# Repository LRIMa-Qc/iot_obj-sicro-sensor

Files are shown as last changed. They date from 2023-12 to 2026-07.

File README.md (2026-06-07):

# iot_obj-sicro-sensor

Authors : LRIMa (Laboratoire de Recherche Informatique de Maisonneuve)

## Repo composition

```bash
code/
├── actioneur       (esp32 code)
├── broadcaster     (sensor code [nrf52833])
├── central         (python BLE scanning and ALIVEcode integration)
└── central-nrf     (BLE receiver [nrf52840dongle])
schematic/
├── lrima-main/     (Main board KiCad project)
└── lrima-ground/   (Ground board KiCad project)
models/
└── sensor-casing/  (3D CAD models for enclosure)
```

### Physical device

The schematics and PCB were designed using [KiCad](https://www.kicad.org/) EDA software
There is a protective layer that needs to be applied on the ground part of the pcb to prevent corrosion

## Building

#### Tools needed

- VS Code
- [nRF Connect](https://www.nordicsemi.com/Products/Development-tools/nrf-connect-for-desktop)
- [nRF Connect VS Code extension](https://www.nordicsemi.com/Products/Development-tools/nRF-Connect-for-VS-Code)
- nRF toolchain `v3.2.4`
- nRF SDK `v3.2.4`
- J-Link
- Python 3.8+ (for central application)

#### Broadcaster

##### Preparing the environment

Before building the broadcaster program, you **must** make sure that you changed the `CONFIG_BLE_USER_DEFINED_MAC_ADDR` and the `CONFIG_BLE_USER_DEFINED_NAME` so that they are unique. Note that the `CONFIG_BLE_USER_DEFINED_NAME` must end with a number (ex : 01). If you need mac address, you can use this [mac address generator](https://dnschecker.org/mac-address-generator.php).

##### Building

The broadcaster uses the **sysbuild** system from NCS v3.2.4. To build the program for the nrf52833 using the [nRF Connect VS Code extension](https://www.nordicsemi.com/Products/Development-tools/nRF-Connect-for-VS-Code):

1. Open the broadcaster folder in VS Code
2. Use the nRF Connect extension to build using the `lrima_greenhouse_nrf52833` board
3. Flash using the [extension flashing options](https://nrfconnect.github.io/vscode-nrf-connect/get_started/quick_debug.html#how-to-flash-an-application)

Note: If flashing fails, use the `erase and flash` option to perform a full erase first.

###### J-Link setup

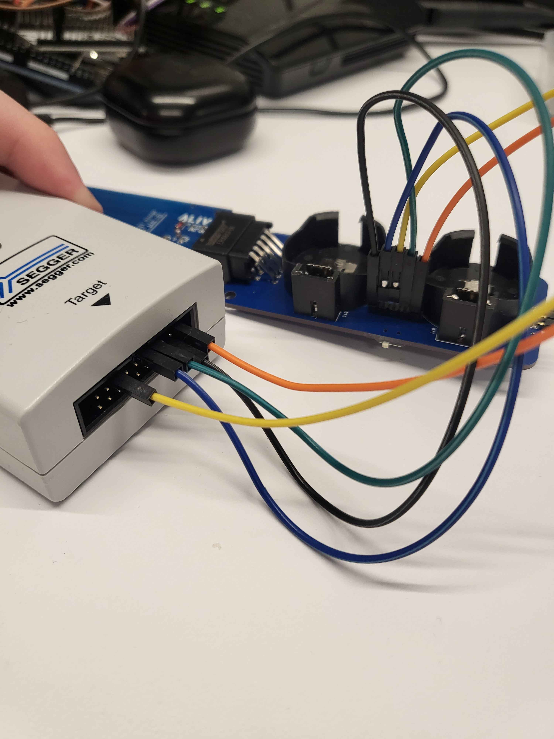
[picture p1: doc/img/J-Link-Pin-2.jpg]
J-Link setup

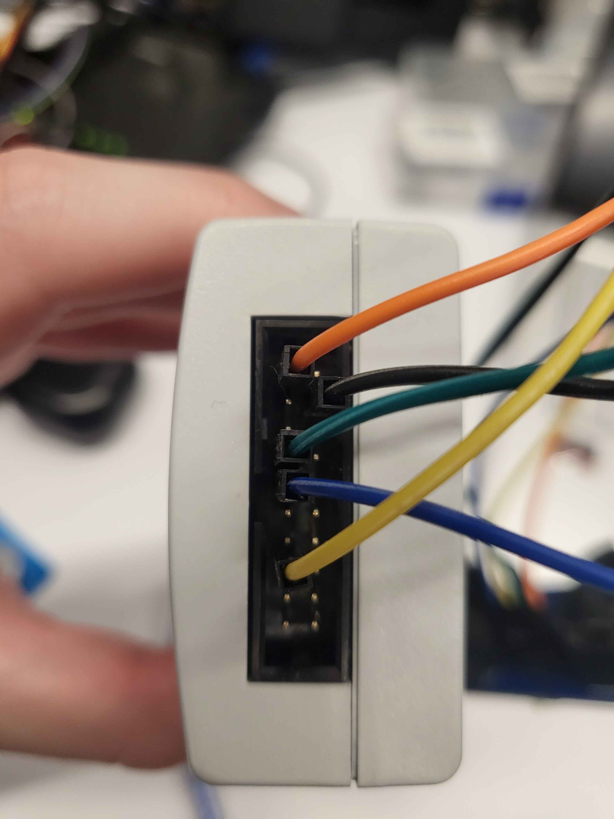
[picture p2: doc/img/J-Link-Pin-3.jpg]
J-Link setup 2

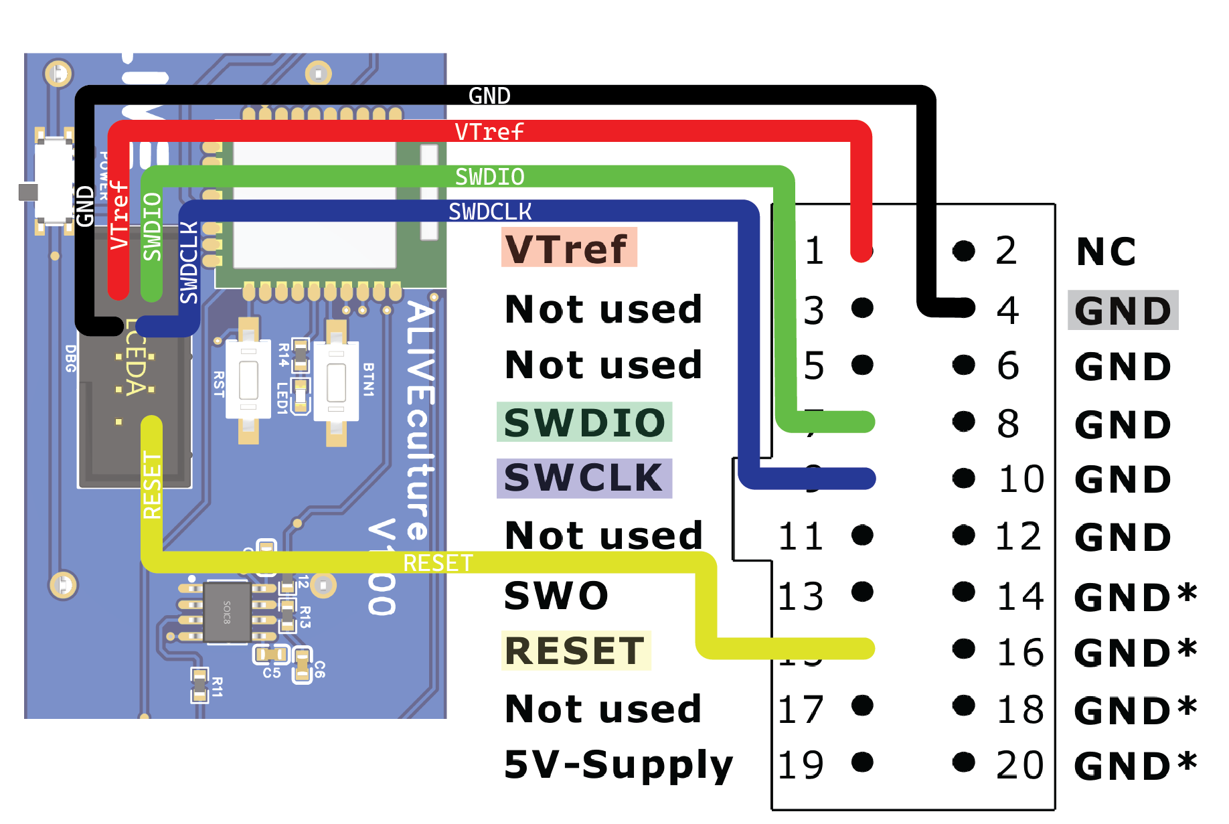
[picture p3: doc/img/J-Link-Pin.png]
J-Link setup 3


#### Firmware over the air update (DFU)

The board supports over-the-air firmware updates. To prepare an update:

1. Build the application as described above
2. Locate the signed image in the sysbuild app domain: `build/broadcaster/zephyr/zephyr.signed.bin`
3. Transfer this file to your phone
4. Press and hold button1 until the LED is on, then release
5. You will have up to 60 seconds (configurable via `CONFIG_BLE_DFU_ADV_DURATION_SEC`) to start the update
6. Use the [nRF Connect mobile app](https://www.nordicsemi.com/Products/Development-tools/nrf-connect-for-mobile) to connect to the device (named with your `CONFIG_BLE_USER_DEFINED_NAME`)
7. Go to the `DFU` tab and select `zephyr.signed.bin`
8. Press `Upload` and monitor the progress

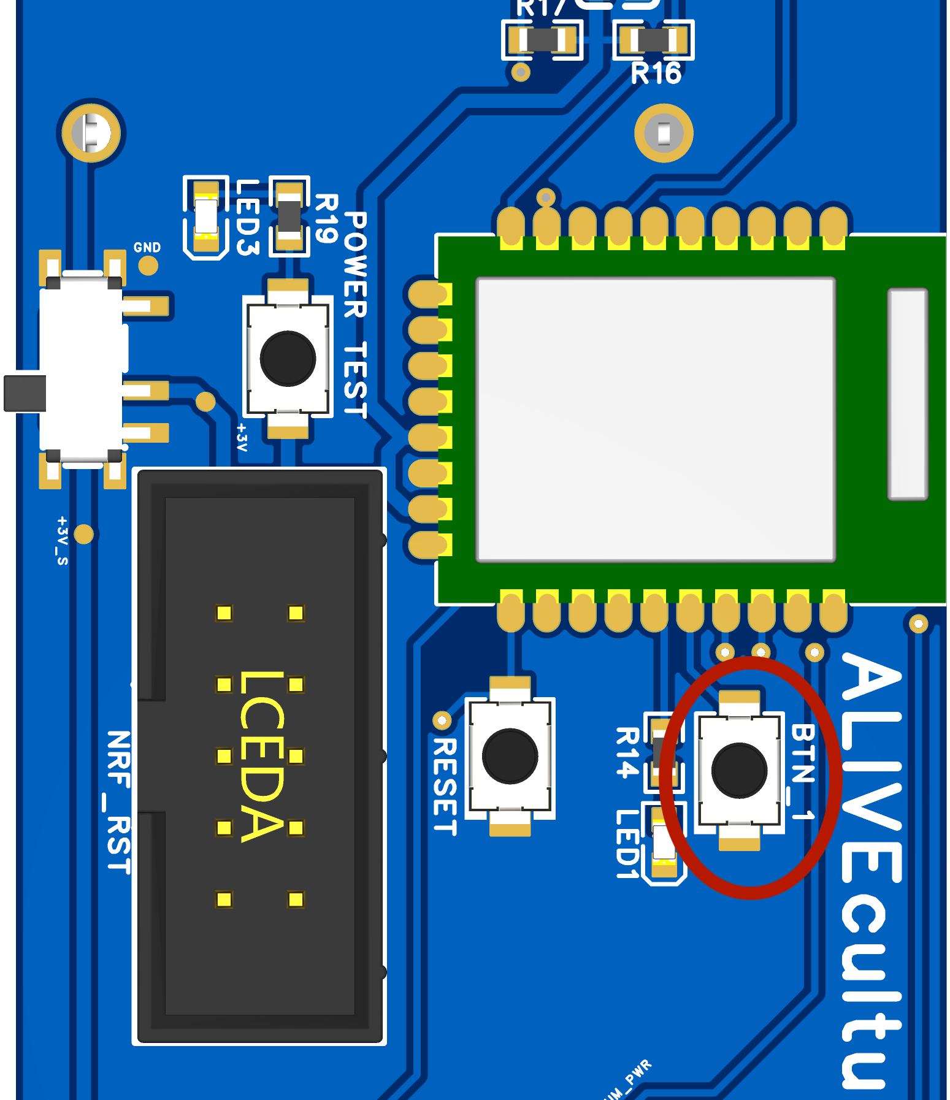
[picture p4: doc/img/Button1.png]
Button1


#### Device Functionality

The broadcaster uses a single BLE advertising workflow. It sends sensor data uplink and then opens a short scan window to receive a downlink sleep update when needed. The user can wake up the device at any time by pressing button1. There is never a connection established, and all communication is done through advertisements and scan responses.

##### Broadcaster

The broadcaster collects sensor data and transmits it BLE advertisements:

**Supported sensors:**

- Temperature/Humidity (SHT4X)
- Soil temperature/moisture/conductivity (STCC4)
- CO2 concentration

**Transmission behavior:**

- Sends data at intervals specified by `CONFIG_SENSOR_SLEEP_DURATION_SEC`
- Uses BLE advertising for the duration specified in `CONFIG_BLE_ADV_DURATION_SEC`
- Publishes a 29-byte service payload containing company ID, node ID, sequence, sleep duration, sensor values, and a presence bitmap
- Opens an active scan window after uplink to receive sleep updates sent by the central
- Beacon payload structure is shown below:

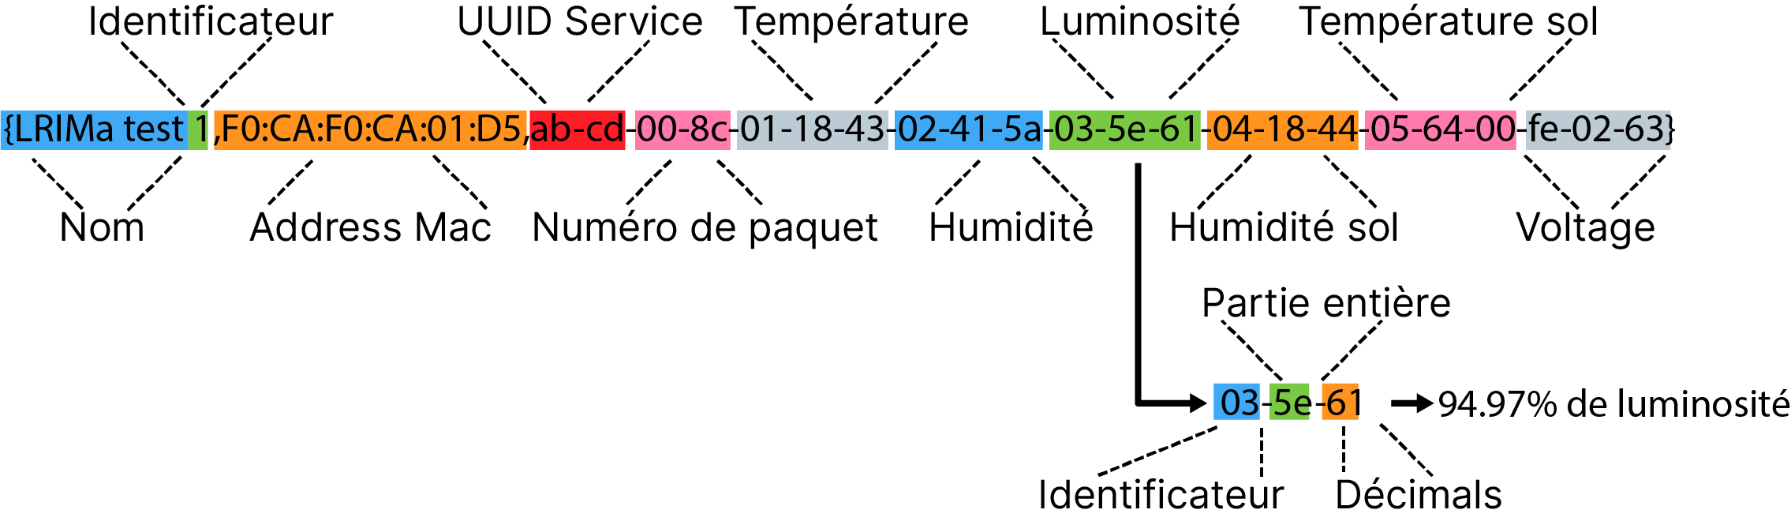
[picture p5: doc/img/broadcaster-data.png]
Broadcaster data.


> **Note:** The diagram above predates the latest payload format. See the broadcaster documentation for the full 29-byte layout and presence bitmap details.

### Central-nrf

The central-nrf firmware runs on the nRF52840 dongle to receive BLE broadcasts from the broadcaster.

**Building:**

1. Use the [nRF Connect VS Code extension](https://www.nordicsemi.com/Products/Development-tools/nRF-Connect-for-VS-Code) to build for `nrf52840dongle_nrf52840` board
2. Flash using the nRF Connect for Desktop programmer tools
3. Put the device in [DFU mode](https://infocenter.nordicsemi.com/index.jsp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)
4. Flash the `build/zephyr/zephyr.hex` file

### Central (Python Application)

The central application handles BLE scanning, data collection, and integration with ALIVEcode.

**Core modules:**

- `core/storage.py` - Persistent data management
- `core/payload.py` - Sensor data parsing and validation
- `core/aliot_sync.py` - ALIVEcode cloud integration
- `core/downlink_advertiser.py` - BlueZ D-Bus advertiser for sleep-time downlink frames
- `core/health.py` - System health monitoring
- `core/config.py` - Configuration management

**Setup and running:**

1. Plug the Central-nrf dongle into a computer or Raspberry Pi
2. Configure the application:
   - Copy `config.ini.example` to `config.ini`
   - Set your `object_id` and `auth_token` from your [ALIVEcode.ca](https://ALIVEcode.ca) IoT project

3. Install dependencies:

   ```bash
   # For Raspberry Pi 4
   pip install -r requirements_pi4.txt

   # For Raspberry Pi 5
   pip install -r requirements_pi5.txt
   ```

   (Using a Python virtual environment is recommended)

   `dbus-next` is required because downlink sleep updates are emitted through BlueZ D-Bus advertising APIs.

4. Run the application:

   ```bash
   python main.py
   ```

5. Power on the broadcaster devices

The application will automatically scan for broadcaster devices, collecting sensor data and synchronizing with ALIVEcode.
It publishes each node under `/doc/<device_index>` including `/doc/<device_index>/sleep_duration_sec`, and uses `/doc/sleep_time` as the desired target for downlink sleep updates.

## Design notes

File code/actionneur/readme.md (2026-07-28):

# Actionneur

## Description

This folder contains the code for the esp32 that controls relays from ALIVEcode.

## How to use

### Seting up the secrets

You must setup the `SECRET.h` file witht the `SSID` and `PASSWORD` of the wifi network you want to connect to.
Also you need to set the `AUTH_TOKEN` and `OBJECT_ID` from the device page on ALIVEcode.
The `SECRET.h` file should look like this:

```c++
/**
 * Fill in the credentials below
 * For the Wifi and the Aliot credentials
*/

// Setup wifi credentials
#define SSID "SSID"
#define PASSWORD "PASSWORD"

// Setup aliot credentials
#define AUTH_TOKEN "AUTH_TOKEN"
#define OBJECT_ID "OBJECT_ID"
```

### Setting up the relays

You need to setup the relays in the `main.cpp` file.

#### Defining the relays

The relays are defined in the `valves` array. like this:

```c++
const Valve valves[] = // Changed to an array
    {
        {
            .actionId = "valve_1",
            .pin = 2,
            .isPinInverted = true
        },
        {
            .actionId = "valve_2",
            .pin = 4,
            .isPinInverted = true
        }
    };
```

_Note : You can not have more relay than the value of `MAX_ACTION_COUNT` in `Aliot-C` (the default value is 5)_

- The `actionId` field is the id of the action _and_ the field value on ALIVEcode.
- The `pin` field is the pin number on the esp32.
- The `isPinInverted` field is used to invert the pin state. (If the relay is active when the pin is low, set this to `true`)

#### Adding the callbacks

For each relay you need to add the following bit of code:
`main.cpp` callback function:

```c++
// Function to be called when valve 1 state is changed on ALIVEcode
bool callbackValve1(const char* data) {

    Serial.print("New valve 1 state:");
    Serial.println(data);

    // Set valve 1 state
    setValveState(valves[0], stringToBool(data));

    return true;
}

void setup() {
    // ...

    // Add the callback to the valve 1
    addCallback(valves[0].actionId, callbackValve1);

    // ...
}
```

### Adding controls on AliveCode

1. Create a toggle component
2. Set the toggle to be controlled by the document with `actionID`
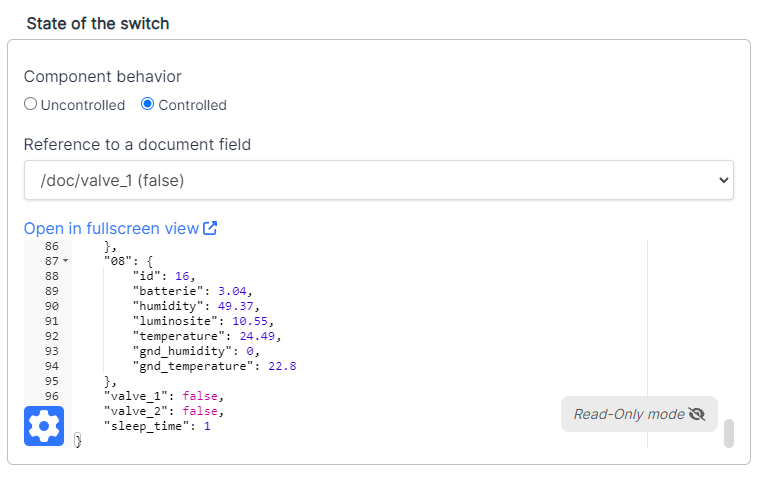
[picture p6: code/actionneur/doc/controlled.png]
controlled image
   
3. Set the Id of the action to the `actionID`
   ActionID image
4. Repeat 1-3 for each relay in the list

### Updating the wifi credentials remotely

The device exposes a `wifi_config` action that lets you push new wifi credentials from the ALIVEcode dashboard without re-flashing the device.

1. Create an action component with `actionID` set to `wifi_config`.
2. Configure the action's payload value to be a JSON string of the form:

   ```json
   { "ssid": "MyNetwork", "password": "MyPassword" }
   ```

3. When received, the device saves the new credentials to non-volatile storage (NVS) and switches to the new network. The `SSID`/`PASSWORD` values in `SECRET.h` are only used as a fallback on first boot, before any `wifi_config` action has ever been received; afterwards, the stored credentials always take precedence.

> **Warning**: if the new credentials are invalid, the device will fail to connect, restart, and retry with the same (bad) saved credentials on every subsequent boot — there is currently no automatic fallback to the last-known-good network. Double check the SSID/password before sending this action.

_Note: credential persistence relies on the ESP32 `Preferences` (NVS) API. On `esp8266`/`native` builds the `wifi_config` action is still registered and will switch networks for the current session, but nothing is persisted — the hardcoded `SECRET.h` credentials are used again on the next boot._

### Installing the libraries

The project uses platformio to manage the libraries. You can install it from [here](https://platformio.org/install/ide?install=vscode).
After installing platformio, you need to install the libraries. You can do this by opening the project in vscode and clicking on the `PlatformIO: Build` button in the bottom left corner. (The library installation should start automatically)

#### Libraries used

- [ArduinoJson](https://arduinojson.org/)
- [Aliot-C](https://github.com/LRIMa-Qc/aliot-c)
- [WiFiClientSecure](https://www.arduino.cc/en/Reference/WiFiClientSecure)
- [ArduinoHttpClient](https://www.arduino.cc/reference/arduinohttpclient/)

### Uploading

#### Connection

First plug the esp32 to your computer using a FTDI Mini Usb to Serial adapter [https://www.amazon.ca/dp/B0CBBKXVQV](https://www.amazon.ca/dp/B0CBBKXVQV)

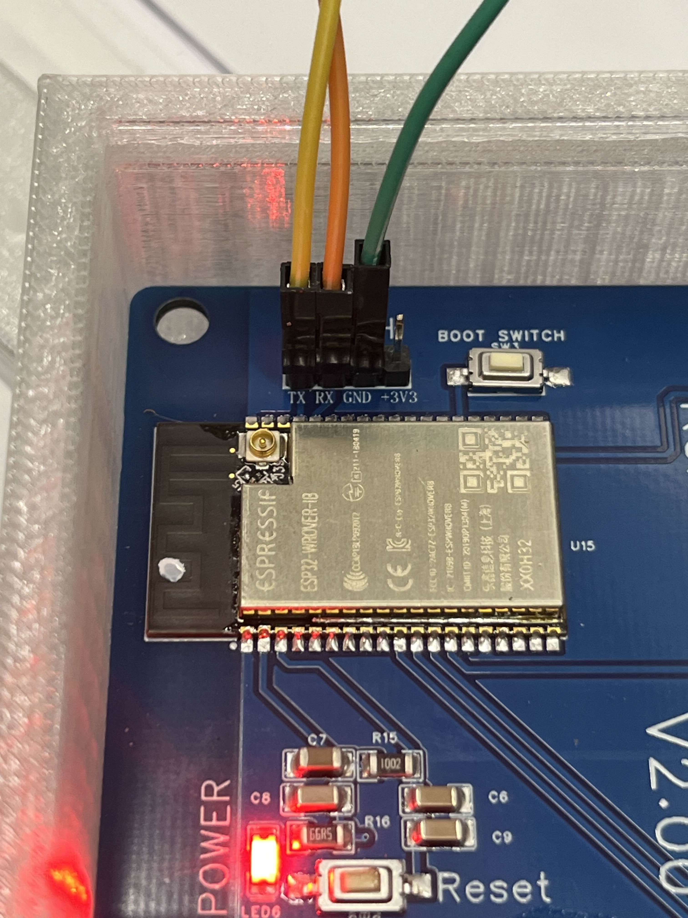
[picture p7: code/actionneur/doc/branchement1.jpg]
Branchements #1

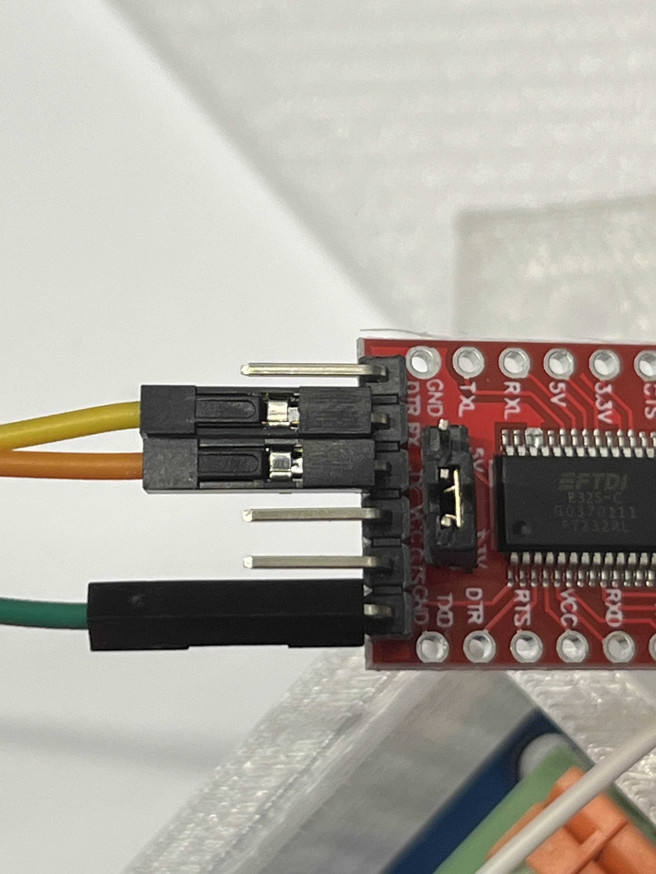
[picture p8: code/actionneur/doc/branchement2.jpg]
Branchements #2


See the table below for the connections:

| Relais | FTDI |
| --- | ---- |
| RX | TX |
| TX | RX |
| GND | GND  |

#### Uploading the code

You can upload the code to the esp32 by clicking on the `PlatformIO: Upload` button ( ➡️ ) in the bottom left corner of vscode. (You need to have the esp32 connected to your computer)

#### Relay board specific

1. You need to set the board in `Boot` mode to upload the code.
   > (You can do this by shorting the `BOOT` header before connecting the esp32 to power)
2. After the board is powered, you can unshort the `BOOT` header.
3. You need to make sure that all the `DIP` switches are set to the relay side.
   > (If you don't do it, the board won't flash properly. This is due to the fact that `PIN 12` must be set to `low`)

### Monitoring the serial output

You can monitor the serial output by clicking on the `PlatformIO: Serial Monitor` button ( 🔌 ) in the bottom left corner of vscode. (You need to have the esp32 connected to your computer)

### Connecting components (ex: Fans, Lights, etc.)

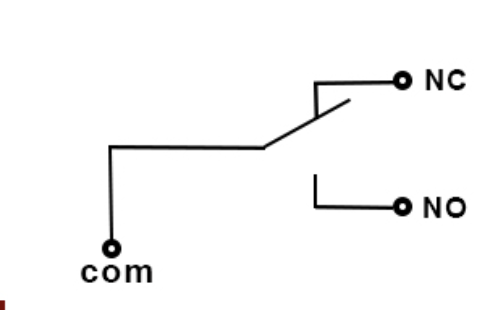
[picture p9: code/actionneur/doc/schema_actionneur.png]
Connection components


Connect into the COM (middle) the voltage source (anything between 0V to 220V) and the NO (Normally Open) the component you want to control. You can connect the NC (Normally Closed) to the component if you want to invert the relay state.

In simpler terms:

1. When the relay is activated, the power from the COM will be sent to the NO.
2. When the relay is deactivated, the power from the COM will be sent to the NC.

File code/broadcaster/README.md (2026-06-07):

# Broadcaster

## Flashing the board

### Tools needed

- VS Code
- [nRF Connect](https://www.nordicsemi.com/Products/Development-tools/nrf-connect-for-desktop)
- [nRF Command line tool](https://www.nordicsemi.com/Products/Development-tools/nRF-Command-Line-Tools/Download)
- [nRF Util](https://www.nordicsemi.com/Products/Development-tools/nrf-util)
- [nRF Connect VS Code extension](https://www.nordicsemi.com/Products/Development-tools/nRF-Connect-for-VS-Code)
- nRF toolchian `v3.2.4`
- nRF SDK `v.3.2.4`
- J-Link

### Preparing the environment

Before building the broadcaster program, you **must** make sure that you changed the `CONFIG_BLE_USER_DEFINED_MAC_ADDR` and the `CONFIG_BLE_USER_DEFINED_NAME` so that they are unique. Note that the `CONFIG_BLE_USER_DEFINED_NAME` must end with a number (ex : 01). If you need mac address, you can use this [mac address generator](https://dnschecker.org/mac-address-generator.php).

These values are used as defaults and are now persisted in flash (settings/NVS) on first boot. If you later change them in configuration, the device will keep the persisted values unless flash settings are erased.

### Building and flashing

To build the program for the nrf52833 you need to use the [NRFconnect](https://www.nordicsemi.com/Products/Development-tools/nRF-Connect-for-VS-Code) extension in vscode and then you just have to [follow the instructions](https://nrfconnect.github.io/vscode-nrf-connect/get_started/build_app_ncs.html#how-to-build-an-application) to build it using the `lrima_greenhouse_nrf52833/nrf52833` board target. After you need to flash it using the [option available in the extension](https://nrfconnect.github.io/vscode-nrf-connect/get_started/quick_debug.html#how-to-flash-an-application).

Note : If the board is giving out an error when flashing try these steps :

1. Check that the J-Link is detected by the computer (Drivers might be needed)
2. Check that the board has power (Use the led test button)
3. Check that the J-Link is properly connected to the board (You can try to press the reset button on the board, the J-Link led should be red when the button is pressed)
4. Try to flash the board using the `erase and flash` option
5. Verify the soldering of the board

To reset persisted settings (`sleep time`, `device name`, `device MAC`, `device node ID`) and re-apply values from `prj.conf`, you must use **erase and flash** (a normal flash keeps existing settings in NVS).

### Startup initialization behavior

When the broadcaster boots, the LED blinks while the remaining drivers are initialized. Once initialization completes, the LED is turned off.

If one of the startup initializations fails, the firmware logs the error, turns the LED on solid for 5 seconds, and then reboots the board.

#### J-Link setup

J-Link setup

### Firmware over the air update (DFU)

The board supports over-the-air updates (OTA) over BLE/MCUmgr.

1. Build the firmware as described above.
2. Use the signed application image from the sysbuild app domain:
   - `build/broadcaster/zephyr/zephyr.signed.bin` (single-image BLE DFU with nRF Connect mobile).
3. Optional multi-image package generated by sysbuild:
   - `build/dfu_application.zip`
4. Press and hold `button1` (see picture) until the LED is on, then release.
5. Start DFU within `CONFIG_BLE_DFU_ADV_DURATION_SEC` seconds.
6. In the [nRF Connect mobile app](https://www.nordicsemi.com/Products/Development-tools/nrf-connect-for-mobile), connect to the device name set in `CONFIG_BLE_USER_DEFINED_NAME`, open `DFU`, select `zephyr.signed.bin`, and upload.

After a successful transfer, the board reboots into the new image.

---

## Unique Device Configuration

Before deploying multiple units, ensure each device has a **unique MAC address**, **descriptive name**, and **node ID**:

Edit **prj.conf**:

```
CONFIG_BLE_USER_DEFINED_MAC_ADDR="f0:ca:f0:ca:01:e8"  # Change per device
CONFIG_BLE_NODE_ID=67                                  # Change per device
# Optional: restrict downlink updates to one gateway MAC
CONFIG_BLE_GATEWAY_MAC_ADDR="aa:bb:cc:dd:ee:ff"
```

**Generate unique MAC address:** Use [MAC Address Generator](https://dnschecker.org/mac-address-generator.php)

Persistence behavior:

- `sleep time`, `device name`, `device MAC`, and `device node ID` are stored in flash through settings/NVS.
- On first boot (or after erase), values from `prj.conf` are used as defaults and saved.
- On next boots, persisted values are loaded from flash.
- To force new defaults from `prj.conf`, perform **erase and flash**.

---

Notes : If the led turns off before you can start the flashing process, keep the button pressed and the sensor will keep advertising until you release the button.

For MCUboot image versioning, this project uses the root `VERSION` file instead of `CONFIG_MCUBOOT_IMAGE_VERSION`.

Button1

## Device Functionality

The device uses a single BLE advertiser. It broadcasts sensor data to the central and does not accept BLE connections or pairing in normal operation.

The user can wake up the device at any time by pressing the button1.

### Broadcaster

The broadcaster sends data at the interval specified in `CONFIG_SENSOR_SLEEP_DURATION_SEC`. It uses legacy BLE advertising, not extended advertising, for the duration specified in `CONFIG_BLE_ADV_DURATION_SEC`. The service data is carried in the advertisement payload and the device name is placed in scan response data to keep the advertisement within the legacy 31-byte limit. The current sleep duration is included in the service payload so the central can publish it and decide whether a downlink update is actually needed.
Broadcaster data.

#### Broadcast payload (service data)

The broadcast service data is 29 bytes long and is encoded as follows:

| Offset | Len | Field | Type | Notes |
| --- | --- | --- | --- | --- |
| 0 | 2 | Company ID | uint16 | `0x0059`, little-endian |
| 2 | 2 | Node ID | uint16 | Unique per flashed device |
| 4 | 1 | Sequence counter | uint8 | Increments each wake; wraps at 255 |
| 5 | 4 | Sleep Duration | uint32 | Current node sleep time in seconds |
| 9 | 2 | Air Temperature | int16 | `0.01 °C` |
| 11 | 2 | Air Humidity | uint16 | `0.01 %RH` |
| 13 | 4 | Luminosity | uint32 | Lux |
| 17 | 2 | CO2 | uint16 | PPM |
| 19 | 2 | Ground Temperature | int16 | `0.01 °C` |
| 21 | 2 | Ground Humidity | uint16 | `0.01 %RH` |
| 23 | 2 | Battery Level | uint16 | `0.01 V` |
| 25 | 1 | Presence bitmap | uint8 | Bitmask for optional sensors |
| 26 | 3 | Reserved | uint8[3] | Set to `0x00` |

Presence bitmap bits:

- Bit 0: Air temperature
- Bit 1: Air humidity
- Bit 2: Luminosity
- Bit 3: CO2
- Bit 4: Ground temperature
- Bit 5: Ground humidity
- Bit 6: Battery

Notes:

- Missing sensors are omitted by clearing their presence bit and zeroing their field bytes.
- The broadcaster does not expose a GATT server in normal builds.
- Sensor sleep time still comes from the persisted local settings when the node boots.
- The central reads the reported sleep duration from bytes 5-8 and compares it against its target sleep value before sending a downlink update.
- The device name is still persisted, but it is advertised via scan response rather than primary advertisement data.

#### Downlink sleep update window

During each uplink cycle, the node runs active scanning in parallel with advertising, then keeps scanning for an additional 200 ms tail window. In practice, the scan window duration is `CONFIG_BLE_ADV_DURATION_SEC * 1000 + 200` ms.
If a valid downlink payload is received, the node updates its sleep duration in RAM, may stop BLE activity early, and then persists the updated value through the existing settings flow.

Downlink payload format expected in advertisement/scan response data:

| Offset | Len | Field | Type | Notes |
| --- | --- | --- | --- | --- |
| 0 | 2 | Company ID | uint16 | `0x0059`, little-endian |
| 2 | 2 | Target Node ID | uint16 | Must match node's ID |
| 4 | 4 | Sleep Duration | uint32 | Seconds |

When `CONFIG_BLE_GATEWAY_MAC_ADDR` is set, only downlink frames from that MAC address are accepted.
Sleep duration values are clamped to a valid range (minimum `1`, maximum `CONFIG_SENSOR_SLEEP_DURATION_MAX_SEC` when sleep modification is enabled).

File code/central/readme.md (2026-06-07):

# Steps to run the central device

## 0. Manually install BlueZ

We currently need to manually install BlueZ to get the latest version. The version in the apt repository is too old (`5.66`) and has some bugs.
We know that currently BlueZ `5.82` works well with the project. These steps can therefore be skipped if you have already installed BlueZ `5.82` or later.

Check the version of BlueZ installed on your system with the following command:

```bash
bluetoothd --version
```

If the version is less than `5.82`, you can follow these steps to install the latest version of BlueZ:

Install the dependencies:

```bash
sudo apt update
sudo apt install -y libdbus-1-dev libglib2.0-dev libudev-dev libical-dev libreadline-dev libusb-dev
```

Download the `5.82` version of BlueZ from the official website:

```bash
cd ~
wget https://www.kernel.org/pub/linux/bluetooth/bluez-5.82.tar.xz
tar xvf bluez-5.82.tar.xz
cd bluez-5.82
```

Compile and install BlueZ:

```bash
./configure --prefix=/usr --mandir=/usr/share/man \
				--sysconfdir=/etc --localstatedir=/var
make -j$(nproc)
sudo make install
```

Reload the Bluetooth service:

```bash
sudo systemctl daemon-reexec
sudo systemctl daemon-reload
sudo systemctl restart bluetooth
sudo systemctl enable bluetooth
```

Verify the installation:

```bash
sudo systemctl status bluetooth
```

> Should show `active (running)` if the installation was successful.

```
bluetoothd --version
```

> Should show `5.82` or later if the installation was successful.

## 1. Initialize the project and the venv

```bash
python3 -m venv venv
source venv/bin/activate
# Raspberry Pi 4
pip install -r requirements_pi4.txt

# Raspberry Pi 5
pip install -r requirements_pi5.txt
```

`dbus-next` is required for Pi downlink advertising (BlueZ D-Bus LEAdvertisement1).
If you install packages manually, ensure this dependency is present.

## 2. Run the project with the following command

```bash
python main.py
```

The central publishes each broadcaster under `/doc/<device_index>` and includes the node's reported sleep interval at `/doc/<device_index>/sleep_duration_sec`.

Sleep updates are received from ALIVEcode on `/doc/sleep_time`, and they are sent to nodes via short BlueZ advertisements.

# USING SERVICES

## 1. Install PM2

First download npm

```bash
sudo apt-get install npm
```

Then download pm2 globally using npm

```bash
sudo npm i -g pm2
```

## 2. For using PM2 as the service manager, modify the file pm2.json to your needs and run the following command

### NOTE: You must have pm2 installed globally and the venv must be created and the requirements must be installed

```bash
pm2 start pm2.json
```

### To automatically start the service on boot, run the following command.

### NOTE : Read the output of `pm2 startup` !! You will have a command to paste in the terminal!

```bash
pm2 save
pm2 startup
```

# KNOWN ERRORS

# If downlink advertisements fail with D-Bus errors

1. Check that BlueZ is `5.82` or later.
2. Check that bluetooth service is running.
3. Check that the process has permission to access the system D-Bus and BlueZ advertising manager.

# If there is an error saying the ble device is not found, try the following steps

## 1. try to run the following command

```bash
sudo bluetoothctl power on
```

### if the above command works, then you can add the following line to the file /etc/rc.local

```bash
sudo bluetoothctl power on
```

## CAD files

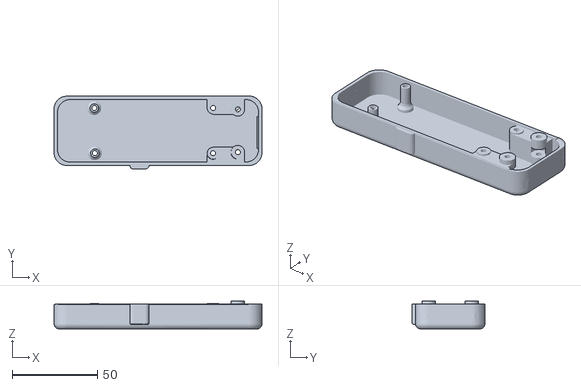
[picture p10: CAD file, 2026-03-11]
models/sensor-casing/BottomPartWithSolar.stl
122.0 x 42.7 x 16.4

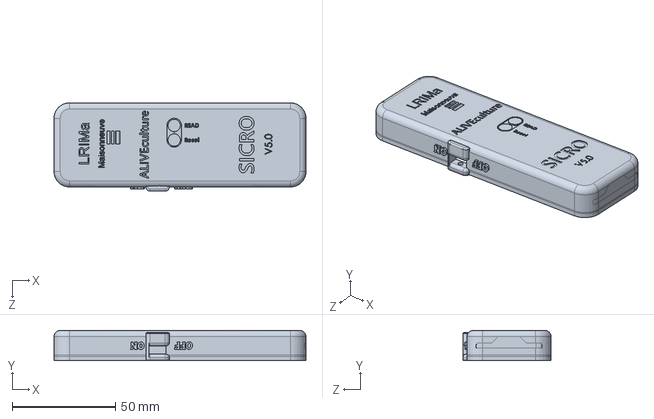
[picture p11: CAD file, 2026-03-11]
models/sensor-casing/TopPart2.SLDPRT
121.9 x 14.6 x 42.7 mm

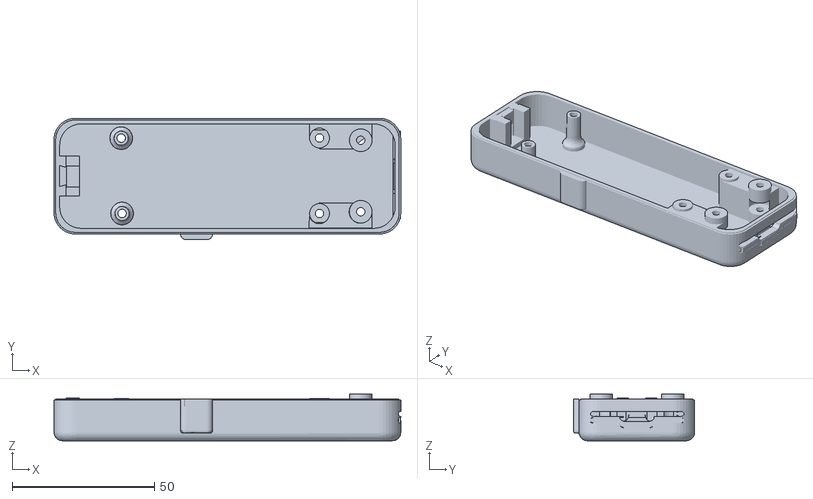
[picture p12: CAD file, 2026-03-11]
models/sensor-casing/Bottom part 4.1.stl
122.0 x 42.7 x 16.4

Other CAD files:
models/sensor-casing/BottomPart3.stl
models/sensor-casing/TopPart3.stl
models/sensor-casing/Bottom part 4.stl
models/sensor-casing/BottomPart.f3d
models/sensor-casing/TopPart.f3d

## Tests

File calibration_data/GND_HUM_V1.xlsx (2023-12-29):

DRY |  | HUMIDE
V | Raw | V | Raw
3.2 | 1692 | 3.2 | 797
3.1 | 1666 | 3.1 | 775
3 | 1645 | 3.06 | 767
2.98 | 1637 | 2.95 | 745
2.8 | 1597 | 2.81 | 713
2.74 | 1579 | 2.72 | 691
2.55 | 1528 | 2.62 | 665
2.3 | 1438 | 2.53 | 639
2.24 | 1415 | 2.4 | 596
2.4 | 1476 | 2.36 | 585
2.35 | 1461 | 2.26 | 544
2.14 | 1378 | 2.2 | 534
1.96 | 1293 | 2.08 | 469
2.05 | 1328 | 2.07 | 468
2.1 | 1354 | 2.03 | 433

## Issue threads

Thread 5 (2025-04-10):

Central stop getting data after 30min

Nilon123456789, 2025-04-10:
The central is stopping to receiving the data after 30min. We can still see that the sensors are sending data using our smartphone.

Nilon123456789, 2025-04-10:
Rebooting the pi after the issue solves the issue

Nilon123456789, 2025-04-10:
Rebooting the python doesn't solve the issue

Nilon123456789, 2025-04-10:
The current Bluetooth adapter is using a ATS2851 chip set

Nilon123456789, 2025-04-17:
Error might be coming from the BlueZ driver (https://github.com/hbldh/bleak/issues/1347)

Nilon123456789, 2025-04-17:
Currently build on the Pi BlueZ 5.82 and running tests to see if it helps

Nilon123456789, 2025-04-17:
Error probably related to theses BlueZ logs
```
Apr 17 18:17:54 raspberrypi bluetoothd[492]: src/device.c:device_new() Unable to register device interface for 00:00:00:00:00:00
Apr 17 18:17:54 raspberrypi bluetoothd[492]: Unable to create object for found device 00:00:00:00:00:00
```

Nilon123456789, 2025-04-20:
Issue was solved with the commit 848cbf4d15da5e002e452c1ccb67c129149aff51. With the BlueZ '5.82` driver and some more optimization in the scanning flow.

Scanning and writing new sleep time is now done sequentially (Scan till detection -> Read -> Write Sleep)

shuhao-dong, 2025-05-02:
Hi, you mentioned "The current Bluetooth adapter is using a ATS2851 chip set", do you mind me asking what specific adapter did you use here? I would also like to use extended advertising in my work. Thank you.

Nilon123456789, 2025-05-02:
> Hi, you mentioned "The current Bluetooth adapter is using a ATS2851 chip set", do you mind me asking what specific adapter did you use here? I would also like to use extended advertising in my work. Thank you.

I used the ugreen CM656 on a raspberry pi.

shuhao-dong, 2025-05-02:
> > Hi, you mentioned "The current Bluetooth adapter is using a ATS2851 chip set", do you mind me asking what specific adapter did you use here? I would also like to use extended advertising in my work. Thank you.
>
> I used the ugreen CM656 on a raspberry pi.

Thank you so much. Before I purchase, I just want to confirm that you used [this](https://gadgman.co.uk/products/ugreen-cm656-usb-bluetooth-5-4-adapter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) dongle with raspberry pi to receive extended advertisements, is this true?

Nilon123456789, 2025-05-02:
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

Yes it is that one.

shuhao-dong, 2025-05-02:
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

My sincere thanks to you.

shuhao-dong, 2025-05-14:
Hi, we've got this dongle as recommended, but it seems like Raspberry Pi does not support it: hci1 command 0x1005 tx timeout. Do you use a custom driver/firmware for this dongle?

Closed 2025-04-20.

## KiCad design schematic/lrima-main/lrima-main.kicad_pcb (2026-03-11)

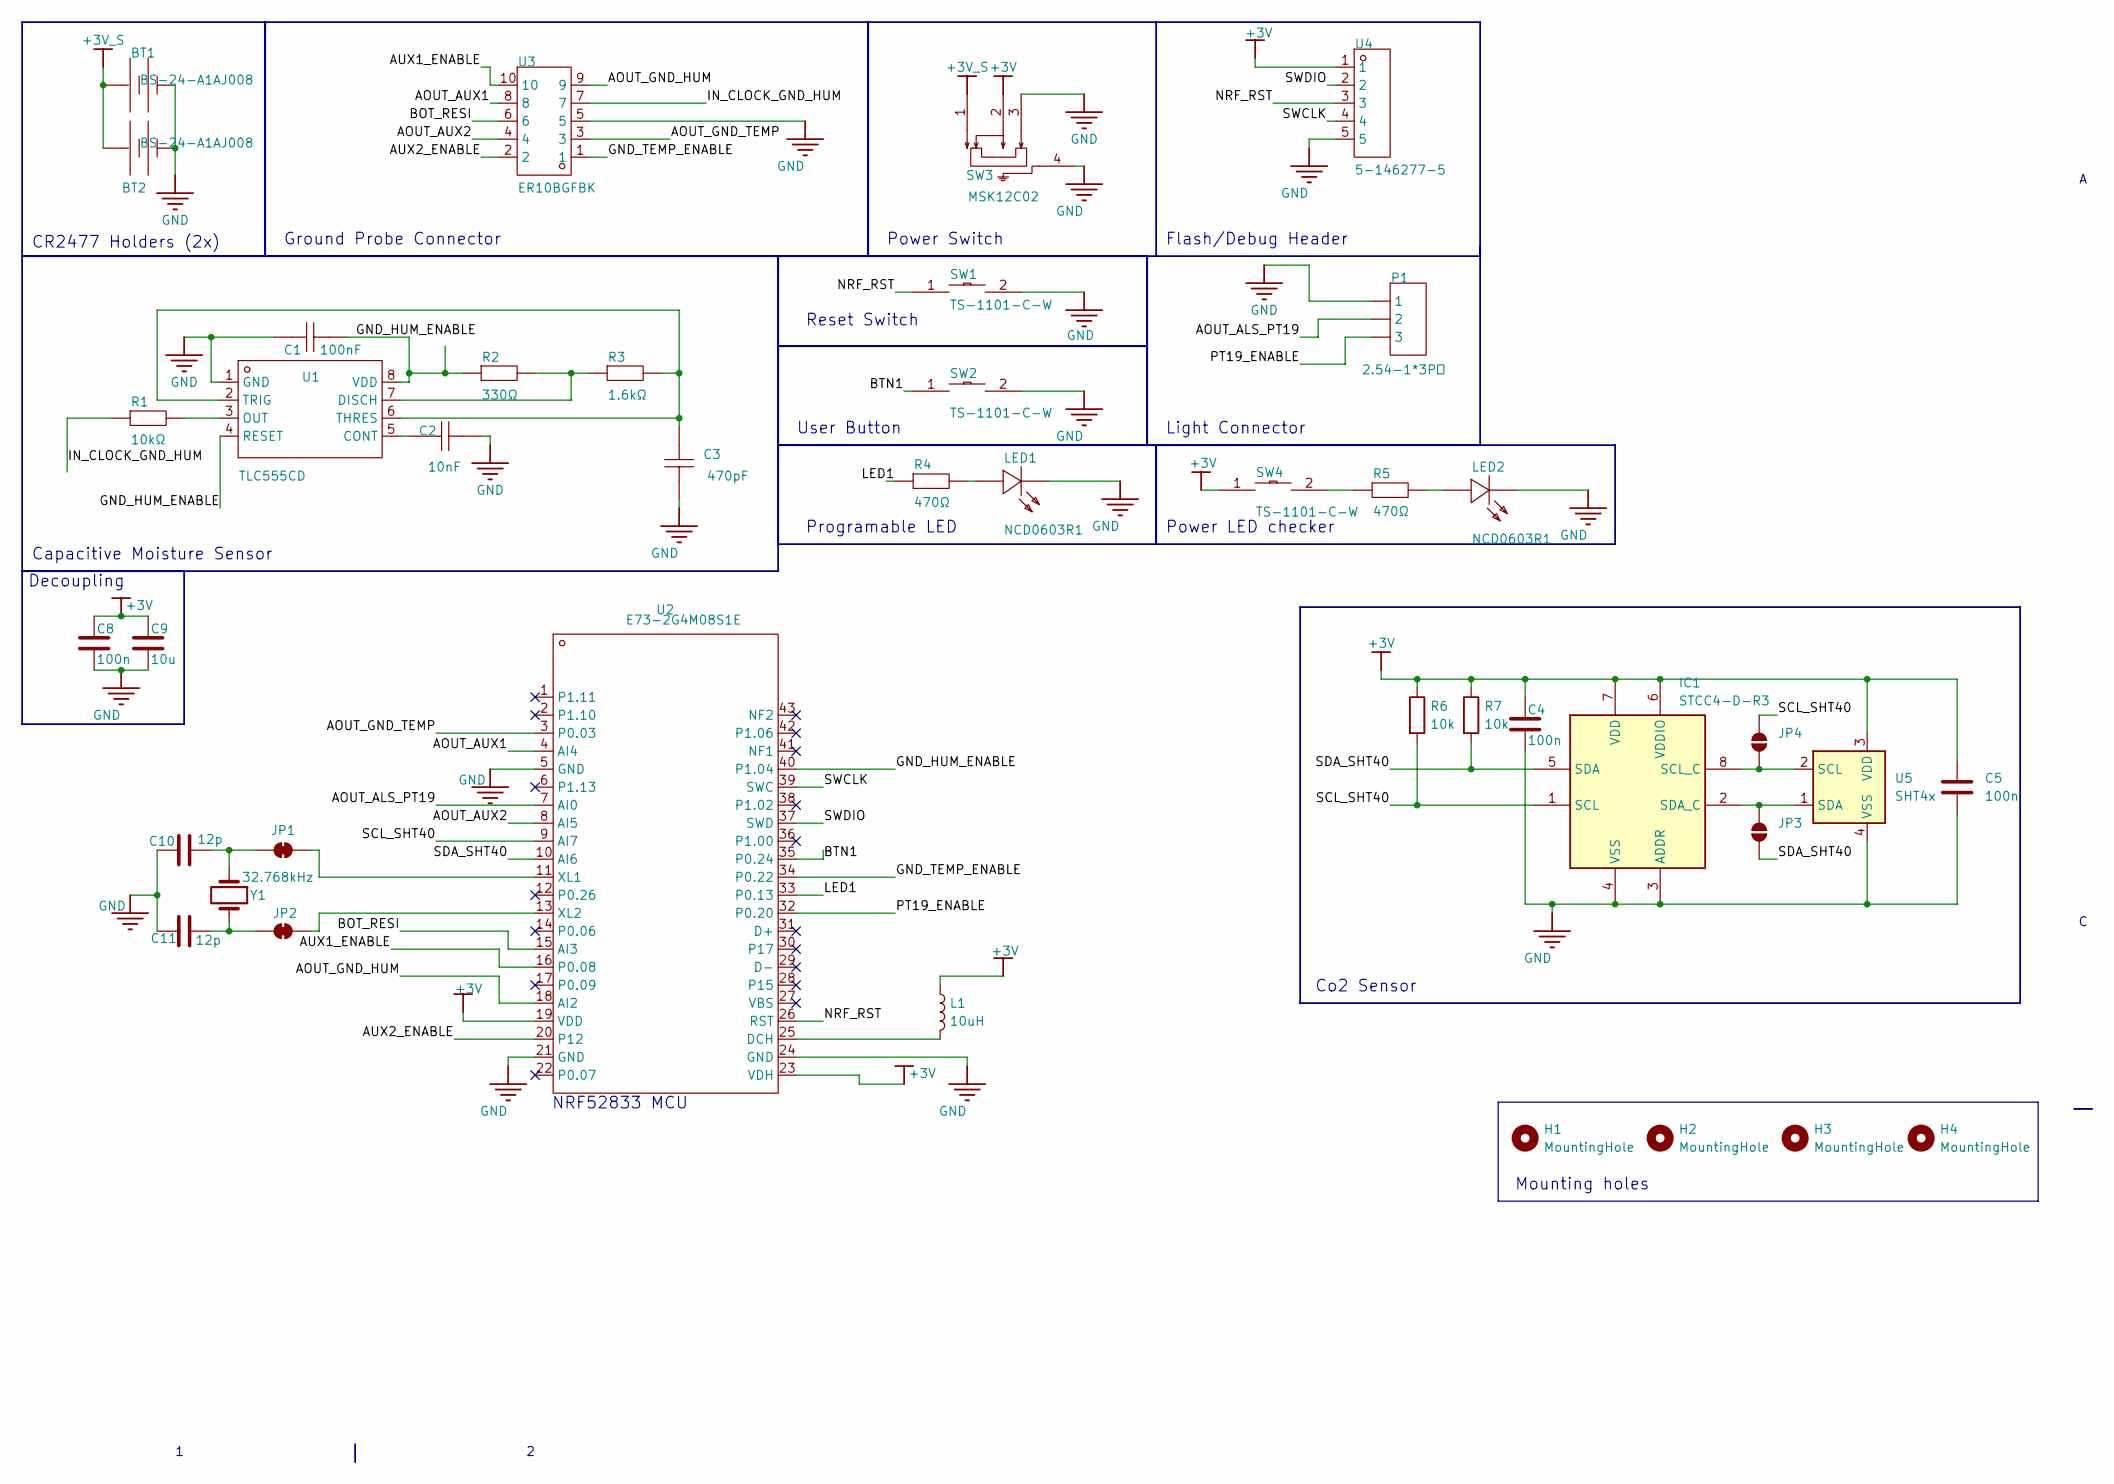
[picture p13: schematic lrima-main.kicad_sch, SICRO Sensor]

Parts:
BT1, BT2: BS-24-A1AJ008; BAT-TH_BS-24-A1AJ013; MANUFACTURER PART BS-24-A1AJ008; LCSC PART NAME 电池底座 适用电池:CR2477
C1: 100nF; C_0603_1608Metric_Pad1.08x0.95mm_HandSolder; TOLERANCE ±10%; MANUFACTURER PART 0603B104K500NT; LCSC PART NAME 100nF ±10% 50V
C2: 10nF; C_0603_1608Metric_Pad1.08x0.95mm_HandSolder; TOLERANCE ±10%; MANUFACTURER PART CC0603KRX7R9BB103; LCSC PART NAME 10nF ±10% 50V
C3: 470pF; C_0603_1608Metric_Pad1.08x0.95mm_HandSolder; TOLERANCE ±10%; MANUFACTURER PART 0603B471K500NT; LCSC PART NAME 470pF ±10% 50V
C4, C5, C8: 100n; C_0603_1608Metric_Pad1.08x0.95mm_HandSolder
C9: 10u; C_0603_1608Metric_Pad1.08x0.95mm_HandSolder
C10, C11: 12p; C_0603_1608Metric_Pad1.08x0.95mm_HandSolder
H1, H2, H3, H4: MountingHole; MountingHole_2.2mm_M2
IC1: STCC4-D-R3; STCC4DR3; Manufacturer_Part_Number STCC4-D-R3
JP1, JP2: SolderJumper-2_P1.3mm_Bridged_RoundedPad1.0x1.5mm
JP3, JP4: SolderJumper-2_P1.3mm_Open_RoundedPad1.0x1.5mm
L1: 10uH; L_0603_1608Metric
LED1, LED2: NCD0603R1; LED_0603_1608Metric_Pad1.05x0.95mm_HandSolder; MANUFACTURER PART NCD0603R1; LCSC PART NAME 红灯
P1: 2.54-1*3P母; PinHeader_1x03_P2.54mm_Horizontal; MANUFACTURER PART 2.54-1*3P母; JLCPCB PART CLASS Extended Part
R1: 10kΩ; R_0603_1608Metric_Pad0.98x0.95mm_HandSolder; TOLERANCE ±1%; MANUFACTURER PART 0603WAF1002T5E; LCSC PART NAME 厚膜电阻 10kΩ ±1% 100mW
R2: 330Ω; R_0603_1608Metric_Pad0.98x0.95mm_HandSolder; TOLERANCE ±1%; MANUFACTURER PART SCR0603F330R; LCSC PART NAME 330Ω ±1%
R3: 1.6kΩ; R_0603_1608Metric_Pad0.98x0.95mm_HandSolder; TOLERANCE ±1%; MANUFACTURER PART 0603WAF1601T5E; LCSC PART NAME 1.6kΩ ±1% 100mW
R4, R5: 470Ω; R_0603_1608Metric_Pad0.98x0.95mm_HandSolder; TOLERANCE ±1%; MANUFACTURER PART 0603WAF4700T5E; LCSC PART NAME 470Ω ±1% 100mW
R6, R7: 10k; R_0603_1608Metric_Pad0.98x0.95mm_HandSolder
SW1, SW2, SW4: TS-1101-C-W; SW-SMD_L6.0-W3.3-LS8.0; VOLTAGE RATING (DC) 12V; MANUFACTURER PART TS-1101-C-W; LCSC PART NAME 立贴 6*3.6*2.5mm 轻触开关 一型3*6*2.5有白ZD b拉伸白色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
SW3: MSK12C02; SW_SPDT_PCM12; MANUFACTURER PART MSK12C02; LCSC PART NAME 两档侧拨贴片 7脚 拨动 白柄 柄长1.5mm,带定位柱
U1: TLC555CD; SOIC-8_3.9x4.9mm_P1.27mm; SUPPLY VOLTAGE 2V~15V; MANUFACTURER PART TLC555CD; LCSC PART NAME 2V~15V
U2: NRF_RST; WIRELM-SMD_E73-2G4M08S1C; MANUFACTURER PART E73-2G4M08S1E; JLCPCB PART CLASS Extended Part
U3: ER10BGFBK; CONN-TH_10P-P2.54_WINGTAT_ER10BGFBK; MANUFACTURER PART ER10BGFBK; JLCPCB PART CLASS Extended Part
U4: 5-146277-5; PinHeader_1x05_P2.54mm_Vertical; CURRENT RATING (MAX) 3A; MANUFACTURER PART 5-146277-5; LCSC PART NAME 间距:2.54mm 直插
U5: SHT4x; SHT4X
Y1: 32.768kHz; Crystal_SMD_3215-2Pin_3.2x1.5mm

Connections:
+3V: C4.1, C5.1, C8.1, C9.1, IC1.6 (VDDIO), IC1.7 (VDD), L1.1, R6.1, R7.1, SW3.2, SW4.1, U2.19 (VDD), U2.23 (VDH), U4.1, U5.3 (VDD)
+3V_S: BT1.1 (+), BT2.1 (+), SW3.1
/AOUT_ALS_PT19: P1.2, U2.7 (AI0)
/AOUT_AUX1: U2.4 (AI4), U3.8
/AOUT_AUX2: U2.8 (AI5), U3.4
/AOUT_GND_HUM: U2.18 (AI2), U3.9
/AOUT_GND_TEMP: U2.3 (P0.03), U3.3
/AUX1_ENABLE: U2.16 (P0.08), U3.10
/AUX2_ENABLE: U2.20 (P12), U3.2
/BOT_RESI: U2.15 (AI3), U3.6
/BTN1: SW2.1, U2.35 (P0.24); also elsewhere on the board
/GND_HUM_ENABLE: C1.1, R2.2, U1.4 (RESET), U1.8 (VDD), U2.40 (P1.04)
/GND_TEMP_ENABLE: U2.34 (P0.22), U3.1
/IN_CLOCK_GND_HUM: R1.1, U3.7
/LED1: R4.1, U2.33 (P0.13)
/NRF_RST: SW1.1, U2.26 (RST), U4.3; also elsewhere on the board
/PT19_ENABLE: P1.3, U2.32 (P0.20)
/SCL_SHT40: IC1.1 (SCL), JP4.2 (B), R6.2, U2.9 (AI7)
/SDA_SHT40: IC1.5 (SDA), JP3.1 (A), R7.2, U2.10 (AI6)
/SWCLK: U2.39 (SWC), U4.4
/SWDIO: U2.37 (SWD), U4.2
GND: BT1.2 (-), BT2.2 (-), C1.2, C2.1, C3.2, C4.2, C5.2, C8.2, C9.2, C10.2, C11.2, IC1.3 (ADDR), IC1.4 (VSS), LED1.1 (K), LED2.1 (K), P1.1, SW1.2, SW2.2, SW3.3, SW3.4, U1.1 (GND), U2.5 (GND), U2.21 (GND), U2.24 (GND), U3.5, U4.5, U5.4 (VSS); also elsewhere on the board
unnamed: IC1.8 (SCL_C), JP4.1 (A), U5.2 (SCL)
unnamed: IC1.2 (SDA_C), JP3.2 (B), U5.1 (SDA)
unnamed: JP1.1 (A), U2.11 (XL1)
unnamed: C10.1, JP1.2 (B), Y1.1
unnamed: JP2.1 (A), U2.13 (XL2)
unnamed: C11.1, JP2.2 (B), Y1.2
unnamed: LED1.2 (A), R4.2
unnamed: LED2.2 (A), R5.2
unnamed: R5.1, SW4.2
unnamed: C2.2, U1.5 (CONT)
unnamed: R2.1, R3.2, U1.7 (DISCH)
unnamed: R1.2, U1.3 (OUT)
unnamed: C3.1, R3.1, U1.2 (TRIG), U1.6 (THRES)
unnamed: L1.2, U2.25 (DCH)

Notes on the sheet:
Programable LED
Light Connector
Power Switch
Decoupling
Power LED checker
Capacitive Moisture Sensor
Mounting holes
Ground Probe Connector
Flash/Debug Header
Co2 Sensor
CR2477 Holders (2x)
NRF52833 MCU
User Button
Reset Switch

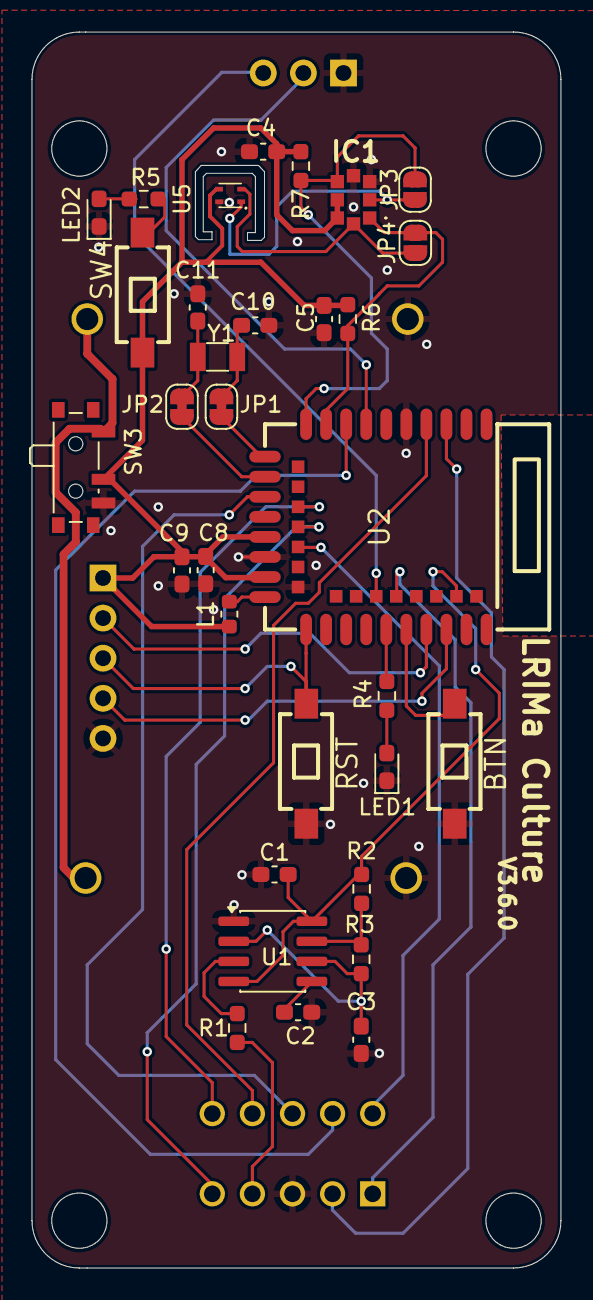
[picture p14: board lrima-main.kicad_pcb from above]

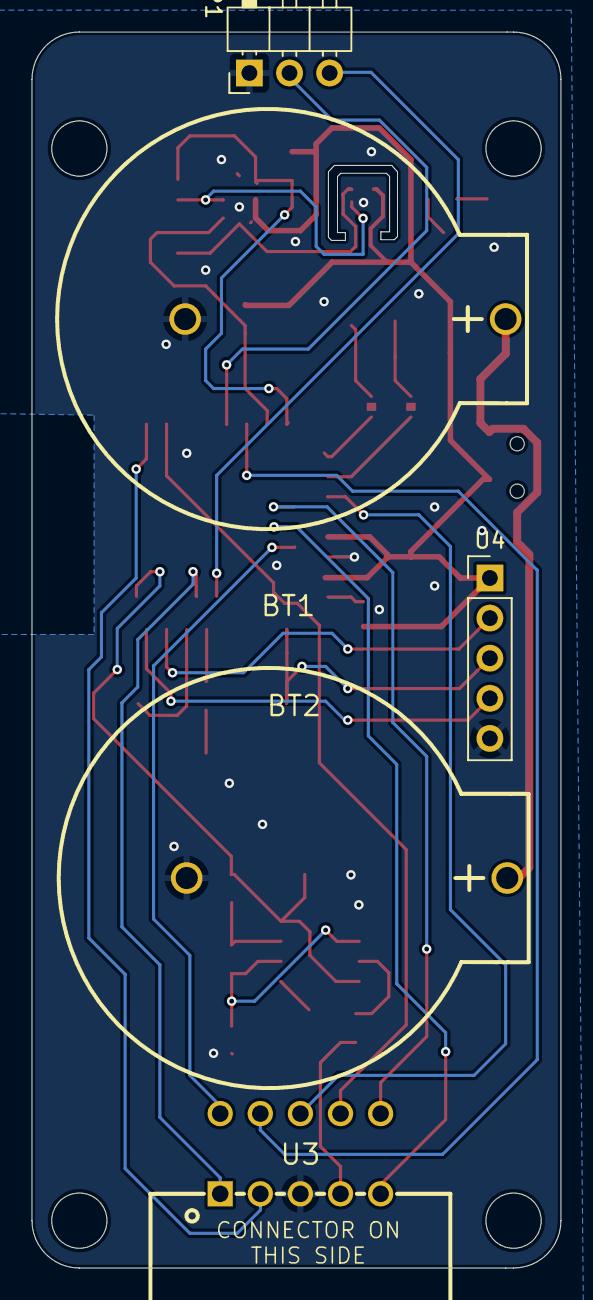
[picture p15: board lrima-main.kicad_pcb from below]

Board: 2 copper layers, 33.5 x 78.3 mm, 41 parts (5 on the bottom side), 36 nets.

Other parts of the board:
BTN: TS-1101-C-W; SW-SMD_L6.0-W3.3-LS8.0
RST: TS-1101-C-W; SW-SMD_L6.0-W3.3-LS8.0

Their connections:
/BTN1: BTN.1; also elsewhere on the board
/NRF_RST: RST.1; also elsewhere on the board
GND: BTN.2, RST.2; also elsewhere on the board

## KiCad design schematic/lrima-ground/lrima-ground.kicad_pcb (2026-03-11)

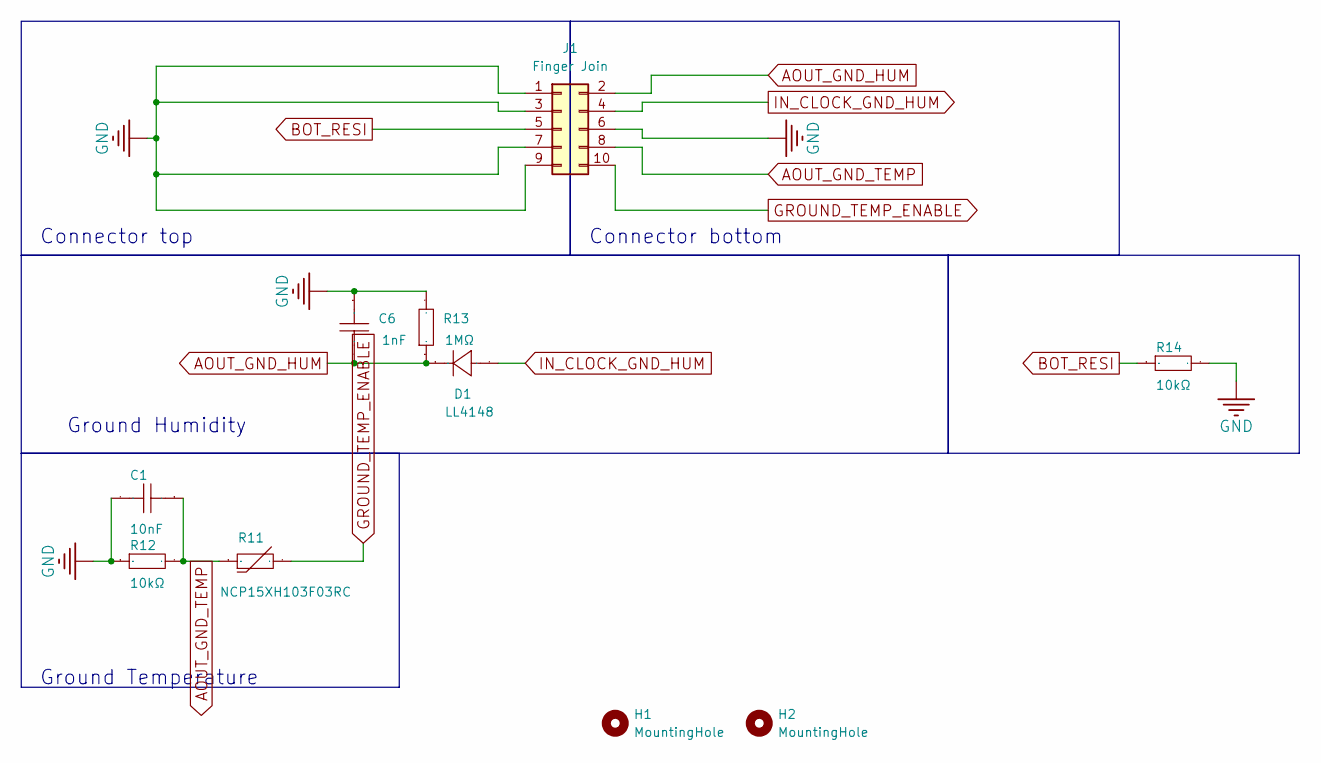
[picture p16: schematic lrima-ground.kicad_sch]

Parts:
C1: 10nF; C_0603_1608Metric; Manufacturer Part CC0603KRX7R9BB103; LCSC Part Name 10nF ±10% 50V
C6: 1nF; C_0603_1608Metric; Manufacturer Part CC0603KRX7R9BB102; LCSC Part Name 1nF ±10% 50V
D1: LL4148; D_MiniMELF; Manufacturer Part LL4148; LCSC Part Name 75V 200mA 4ns
H1, H2: MountingHole; MountingHole_3.2mm_M3
J1: Finger Join; Edge_Finger_5P
R11: NCP15XH103F03RC; R_0402_1005Metric; Manufacturer Part NCP15XH103F03RC; LCSC Part Name 10kΩ 电阻精度:±1% 3380K
R12, R14: 10kΩ; R_0603_1608Metric; Manufacturer Part 0603WAF1002T5E; LCSC Part Name 厚膜电阻 10kΩ ±1% 100mW
R13: 1MΩ; R_0603_1608Metric; Manufacturer Part 0603WAF1004T5E; LCSC Part Name 1MΩ ±1% 100mW

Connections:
AOUT_GND_HUM: C6.2, D1.1 (K), J1.2, R13.1
AOUT_GND_TEMP: C1.1, J1.8, R11.1, R12.2
BOT_RESI: J1.5, R14.1
GND: C1.2, C6.1, J1.1, J1.3, J1.6, J1.7, J1.9, R12.1, R13.2, R14.2
GROUND_TEMP_ENABLE: J1.10, R11.2
IN_CLOCK_GND_HUM: D1.2 (A), J1.4

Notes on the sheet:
Ground Temperature
Connector top
Connector bottom
Ground Humidity

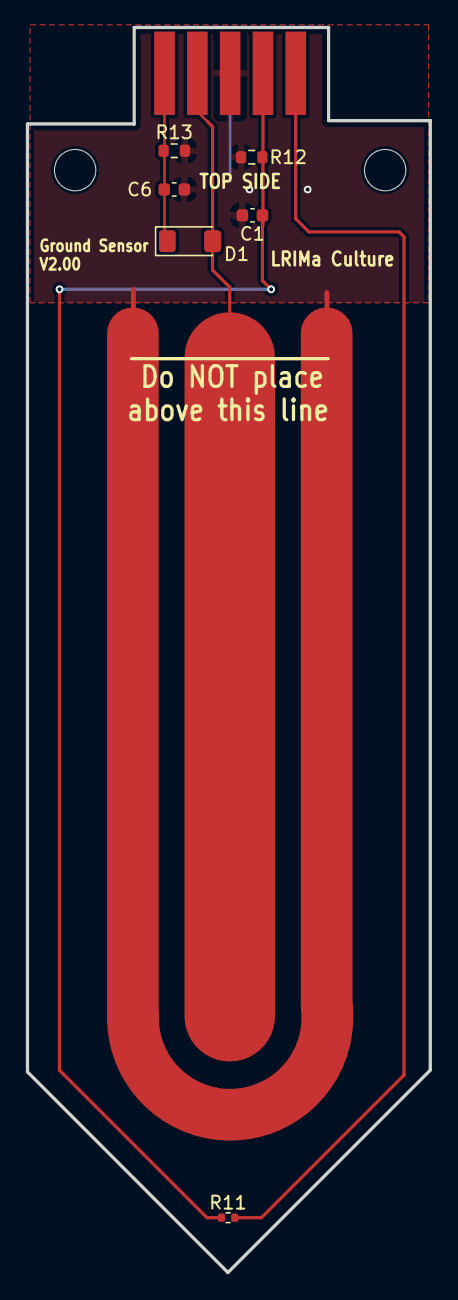
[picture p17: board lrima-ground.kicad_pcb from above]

Board: 2 copper layers, 31.2 x 96.4 mm, 10 parts (1 on the bottom side), 6 nets.

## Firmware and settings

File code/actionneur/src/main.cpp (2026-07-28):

//=============================================================================================================================
//=============================================================================================================================
//! ! ! ! ! ! ! ! ! ! ! ! ! ! ! ! ! ! ! ! ! ! ! ! ! ! ! ! ! ! ! ! ! ! ! ! ! ! !
//! ! ! ! ! ! ! ! ! ! ! ! ! ! ! ! ! ! ! ! ! ! ! ! !

// WARNING: If you plan to use this code with more than 1 valve, you need to
// have a dedicated 5V power supply for the valves

//! ! ! ! ! ! ! ! ! ! ! ! ! ! ! ! ! ! ! ! ! ! ! ! ! ! ! ! ! ! ! ! ! ! ! ! ! ! !
//! ! ! ! ! ! ! ! ! ! ! ! ! ! ! ! ! ! ! ! ! ! ! ! !
//=============================================================================================================================
//=============================================================================================================================

#include "SECRET.h"
#include <AliotObject.h>
#include <ArduinoJson.h>
#include <cstring>

#ifdef ESP32
#include <Preferences.h>
#endif

long lastMillis = 0;
long delayMillis = 500; // 0.5 second

bool isSetupDone = false;

// Serial monitor speed
const int BAUD_RATE = 115200;

// Path for the document
const char *docPath = "/doc/";

// Type def for the valves
typedef struct {
  const char *actionId;
  const uint8_t pin;
  const bool isPinInverted;
} Valve;

// Array of valves
const Valve valves[] = // Changed to an array
    {{.actionId = "valve_1", .pin = 25, .isPinInverted = false},
     {.actionId = "valve_2", .pin = 26, .isPinInverted = false},
     {.actionId = "valve_3", .pin = 27, .isPinInverted = false},
     {.actionId = "valve_4", .pin = 14, .isPinInverted = false},
     {.actionId = "valve_5", .pin = 18, .isPinInverted = false}};

// Crate AliotObject instance
AliotObject aliotObj = AliotObject();

// NVS storage for remotely-updated wifi credentials
#ifdef ESP32
Preferences preferences;
#endif
const char *WIFI_PREF_NAMESPACE = "wifi_cfg";
const char *WIFI_PREF_KEY_SSID = "ssid";
const char *WIFI_PREF_KEY_PASS = "password";

// Currently active wifi credentials (loaded from NVS, falling back to
// SECRET.h on first boot)
String currentSsid;
String currentPassword;

// Set when a wifi_config action has updated currentSsid/currentPassword but
// they haven't been confirmed working (i.e. persisted) yet. Persisting only
// after a confirmed reconnect keeps bad credentials from ever overwriting a
// known-good stored network on NVS.
bool pendingWifiSave = false;

// Convert string to a bool
bool stringToBool(const char *str) { return std::strcmp(str, "true") == 0; }

void setValveState(const Valve &valve, bool state) {
  if (valve.isPinInverted) {
    digitalWrite(valve.pin, !state);
    aliotObj.updateDoc(createDict<bool>(
        Pair<bool>((std::string(docPath) + valve.actionId).c_str(), !state)));
  } else {
    digitalWrite(valve.pin, state);
    aliotObj.updateDoc(createDict<bool>(
        Pair<bool>((std::string(docPath) + valve.actionId).c_str(), state)));
  }
}

// Function to be called when valve 1 state is changed on ALIVEcode
bool callbackValve1(const char *data) {

  Serial.print("New valve 1 state:");
  Serial.println(data);

  // Set valve 1 state
  setValveState(valves[0], stringToBool(data));

  return true;
}

// Function to be called when valve 2 state is changed on ALIVEcode
bool callbackValve2(const char *data) {
  Serial.print("New valve 2 state:");
  Serial.println(data);

  // Set valve 2 state
  setValveState(valves[1], stringToBool(data));

  return true;
}

// Function to be called when valve 3 state is changed on ALIVEcode
bool callbackValve3(const char *data) {
  Serial.print("New valve 3 state:");
  Serial.println(data);

  // Set valve 3 state
  setValveState(valves[2], stringToBool(data));

  return true;
}

// Function to be called when valve 4 state is changed on ALIVEcode
bool callbackValve4(const char *data) {
  Serial.print("New valve 4 state:");
  Serial.println(data);

  // Set valve 4 state
  setValveState(valves[3], stringToBool(data));

  return true;
}

// Function to be called when valve 5 state is changed on ALIVEcode
bool callbackValve5(const char *data) {
  Serial.print("New valve 5 state:");
  Serial.println(data);

  // Set valve 5 state
  setValveState(valves[4], stringToBool(data));

  return true;
}

// Load wifi credentials from NVS, falling back to the hardcoded SECRET.h
void loadWifiCredentials() {
#ifdef ESP32
  preferences.begin(WIFI_PREF_NAMESPACE, true);
  currentSsid = preferences.getString(WIFI_PREF_KEY_SSID, SSID);
  currentPassword = preferences.getString(WIFI_PREF_KEY_PASS, PASSWORD);
  preferences.end();
#else
  currentSsid = SSID;
  currentPassword = PASSWORD;
#endif
  Serial.print("Using wifi SSID: ");
  Serial.println(currentSsid);
}

// Persist new wifi credentials to NVS so they survive reboot. No-op (aside
// from logging) on platforms without Preferences support.
void saveWifiCredentials(const String &ssid, const String &password) {
#ifdef ESP32
  preferences.begin(WIFI_PREF_NAMESPACE, false);
  preferences.putString(WIFI_PREF_KEY_SSID, ssid);
  preferences.putString(WIFI_PREF_KEY_PASS, password);
  preferences.end();
  Serial.println("Wifi credentials saved to NVS");
#else
  Serial.println("Preferences not available on this platform; wifi credentials "
                 "not persisted");
#endif
}

// Function to be called when new wifi credentials are pushed from ALIVEcode.
// Expects `data` to be a JSON string: {"ssid": "...", "password": "..."}
bool callbackWifiConfig(const char *data) {
  Serial.print("New wifi config received: ");
  Serial.println(data);

  StaticJsonDocument<256> doc;
  DeserializationError err = deserializeJson(doc, data);
  if (err) {
    Serial.print("Failed to parse wifi_config payload: ");
    Serial.println(err.c_str());
    return false;
  }
  if (!doc.containsKey("ssid") || !doc.containsKey("password")) {
    Serial.println("wifi_config payload missing 'ssid' or 'password' key");
    return false;
  }

  currentSsid = doc["ssid"].as<String>();
  currentPassword = doc["password"].as<String>();

  // Don't persist yet: if these credentials are bad, setupWiFi() will time
  // out and ESP.restart(), and we want the next boot to fall back to
  // whatever is still saved (or SECRET.h), not retry this bad value forever.
  // onReconnect() persists it once the new network is confirmed working.
  pendingWifiSave = true;

  aliotObj.setupConfig(AUTH_TOKEN, OBJECT_ID, currentSsid.c_str(),
                       currentPassword.c_str());
  // Force a reconnect; aliotObj.loop()'s existing self-healing path picks up
  // the new config on its next iteration
  WiFi.disconnect();

  Serial.println("Switching to new wifi network...");
  return true;
}

// Update all valves from ALIVEcode
void updateValveFromServer() {
  for (int i = 0; i < sizeof(valves) / sizeof(valves[0]);
       i++) { // Updated loop condition
    // Get valve state from ALIVEcode
    String res = aliotObj.getDoc(String(docPath) + String(valves[i].actionId));
    bool state = stringToBool(res.c_str());

    // Set valve state
    setValveState(valves[i], state);

    Serial.println(valves[i].actionId + String(" state updated (state: ") +
                   res + ")");

    // sleep for 0.5 sec
    lastMillis = millis();
    while (millis() - lastMillis < delayMillis) {
      aliotObj.loop();
    }
  }
}

// Called when the wifi is connected again
void onReconnect() {
  Serial.println("Reconnected to ALIVEcode");

  // Only now that the current credentials have proven to work do we persist
  // them, so a bad wifi_config update never overwrites a known-good NVS
  // entry.
  if (pendingWifiSave) {
    saveWifiCredentials(currentSsid, currentPassword);
    pendingWifiSave = false;
  }

  updateValveFromServer();
}

void setup() {
  Serial.begin(BAUD_RATE);

  Serial.println("Starting...");

  loadWifiCredentials();
  aliotObj.setupConfig(AUTH_TOKEN, OBJECT_ID, currentSsid.c_str(),
                       currentPassword.c_str());

  aliotObj.setReconnectCallback(onReconnect);

  // Start connection process and listen for events
  aliotObj.run();

  lastMillis = millis(); // Set lastMillis to current millis

  // Add callback for valve 1
  aliotObj.onActionRecv(valves[0].actionId,
                        callbackValve1); // Corrected actionID to actionId

  // Add callback for valve 2
  aliotObj.onActionRecv(valves[1].actionId,
                        callbackValve2); // Corrected actionID to actionId

  // Add callback for valve 3
  aliotObj.onActionRecv(valves[2].actionId,
                        callbackValve3); // Corrected actionID to actionId

  // Add callback for valve 4
  aliotObj.onActionRecv(valves[3].actionId,
                        callbackValve4); // Corrected actionID to actionId

  // Add callback for valve 5
  aliotObj.onActionRecv(valves[4].actionId,
                        callbackValve5); // Corrected actionID to actionId

  // Add callback for remote wifi credential updates
  aliotObj.onActionRecv("wifi_config", callbackWifiConfig);

  // Setup valve pin
  for (int i = 0; i < sizeof(valves) / sizeof(valves[0]); i++) {
    pinMode(valves[i].pin, OUTPUT);
  }

  Serial.println("Setup done");
}

void loop() {
  aliotObj.loop();

  // Wait for delayMillis to make sure the connection is established
  if (millis() - lastMillis > delayMillis && !isSetupDone) {
    // Get valve state from ALIVEcode
    updateValveFromServer();

    isSetupDone = true;
  }

  // Nothing to do here
}

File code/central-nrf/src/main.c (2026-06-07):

/* main.c - Application main entry point */

/*
 * Copyright (c) 2015-2016 Intel Corporation
 *
 * SPDX-License-Identifier: Apache-2.0
 */
#include <stdio.h>
#include <stdlib.h>
#include <zephyr/sys/printk.h>
#include <zephyr/kernel.h>
#include <zephyr/logging/log.h>
#include <zephyr/bluetooth/bluetooth.h>
#include <zephyr/bluetooth/hci.h>
#include <zephyr/drivers/uart.h>
#include <zephyr/drivers/gpio.h>
#include <string.h>

LOG_MODULE_REGISTER(MAIN, CONFIG_MAIN_LOG_LEVEL);

//==================================================================================================
// Macros for logging
#define STRING(x) #x
#define TO_STRING(x) STRING(x)
#define LOCATION __FILE__ ":" TO_STRING(__LINE__)
#define LOG_IF_ERR(expr, msg)                                   			\
    {                                                        								 	 \
        int ret = (expr);                                    						 	   \
        if(ret) {                                            								   	  \
            LOG_ERR("Error %d: " msg " in " LOCATION, ret);            \
    	}																							   \
	}
//==================================================================================================

//==================================================================================================
// Bluetooth defines
#define COMPANY_ID_LE 0x0059
#define PAYLOAD_SIZE 29
#define BIT_TEMP 0x01
#define BIT_HUM 0x02
#define BIT_LUM 0x04
#define BIT_CO2 0x08
#define BIT_GND_TEMP 0x10
#define BIT_GND_HUM 0x20
#define BIT_BAT 0x40
//==================================================================================================

//==================================================================================================
// UART defines
#define NAME_LEN 30
#define DATA_LEN 30
#define MAX_MYRIO_DATA_LEN 80

#define MAX_DATA_LEN 255

#define TX_BUFF_SIZE 40
#define RX_BUFF_SIZE 10
#define RECEIVE_TIMEOUT 100
//==================================================================================================

static const struct gpio_dt_spec led0 = GPIO_DT_SPEC_GET(DT_ALIAS(led1), gpios);

const struct device *uart1= DEVICE_DT_GET(DT_NODELABEL(uart1));

static uint8_t tx_buf[TX_BUFF_SIZE] = {"Init\n\r"};

static uint8_t rx_buf[RX_BUFF_SIZE] = {0};

typedef struct service_data {
		uint8_t len;
		uint8_t data[DATA_LEN];
};

typedef struct remote_device_t {
		char name[NAME_LEN];
		char addr[BT_ADDR_LE_STR_LEN];
		uint8_t packetNumber;
};

// List of remote devices that have been detected
static struct remote_device_t remoteDevices[100] = {0};

bool isLedOn = false;

static char valueDict[MAX_DATA_LEN] = {0};

static void initValueDict() {
	valueDict[0] = 'P'; // Packet number
	valueDict[1] = 'T'; // Temperature
	valueDict[2] = 'H'; // Humidity
	valueDict[6] = 'C'; // CO2
	valueDict[3] = 'L'; // Luminoisty
	valueDict[4] = 'S'; // Humidity GND
	valueDict[5] = 'V'; // Temperature GND
	valueDict[254] = 'B'; // Battery

}

/**
 * @brief Convert an array of bytes to a string of hex values separated by hyphens
 * 
 * @param array
 * @param length
 * @param result
 * @param resultSize
 * @return int 0 if successful, 1 if error
 */
int convertArray(uint8_t* array, size_t length, char* result, size_t resultSize)
{
    size_t currentIndex = 0;
    for (size_t i = 0; i < length; i++) {
        int bytesWritten = snprintf(result + currentIndex, resultSize - currentIndex, "%02x-", array[i]);
        if (bytesWritten < 0 || bytesWritten >= resultSize - currentIndex) {
            return 1;
        }
        currentIndex += bytesWritten;
    }

    result[currentIndex - 1] = '\0'; // Replace the last hyphen with a null terminator
	return 0;
}

/**
 * @brief Convert the data received from the sensor to a string for the Myrio
 * Ex : I=01P=254T=25.40H=50.00C=42.50L=100.00S=000.00V=000.00B=10.20
 * 
 * @param array
 * @param length
 * @param result
 * @param resultSize
 * @param startIndex
*/
int convertToMyrio(uint8_t *array, size_t length, char *result, size_t resultSize, uint8_t startIndex)
{
	if (length < PAYLOAD_SIZE) {
		return 1;
	}

	uint8_t currentIndex = startIndex;
	uint8_t currentIndex = startIndex;
	uint16_t nodeId = (uint16_t)array[2] | ((uint16_t)array[3] << 8);
	uint8_t sequence = array[4];
	uint8_t presentMask = array[25];

	int bytesWritten = snprintf(result + currentIndex, resultSize - currentIndex, "I=%02uP=%u", nodeId, sequence);
	if (bytesWritten < 0 || bytesWritten >= resultSize - currentIndex) {
		return 1;
	}
	currentIndex += bytesWritten;

	if (presentMask & BIT_TEMP) {
		int16_t temp = (int16_t)((uint16_t)array[9] | ((uint16_t)array[10] << 8));
		bytesWritten = snprintf(result + currentIndex, resultSize - currentIndex, "T=%d.%02d",
				temp / 100, abs(temp % 100));
		if (bytesWritten < 0 || bytesWritten >= resultSize - currentIndex) {
			return 1;
		}
		currentIndex += bytesWritten;
	}

	if (presentMask & BIT_HUM) {
		uint16_t hum = (uint16_t)array[11] | ((uint16_t)array[12] << 8);
		bytesWritten = snprintf(result + currentIndex, resultSize - currentIndex, "H=%u.%02u",
				hum / 100, hum % 100);
		if (bytesWritten < 0 || bytesWritten >= resultSize - currentIndex) {
			return 1;
		}
		currentIndex += bytesWritten;
	}

	if (presentMask & BIT_LUM) {
		uint32_t lum = (uint32_t)array[13] | ((uint32_t)array[14] << 8) |
			      ((uint32_t)array[15] << 16) | ((uint32_t)array[16] << 24);
		bytesWritten = snprintf(result + currentIndex, resultSize - currentIndex, "L=%lu",
				(unsigned long)lum);
				(unsigned long)lum);
		if (bytesWritten < 0 || bytesWritten >= resultSize - currentIndex) {
			return 1;
		}
		currentIndex += bytesWritten;
	}

	if (presentMask & BIT_CO2) {
		uint16_t co2 = (uint16_t)array[17] | ((uint16_t)array[18] << 8);
		bytesWritten = snprintf(result + currentIndex, resultSize - currentIndex, "C=%u", co2);
		if (bytesWritten < 0 || bytesWritten >= resultSize - currentIndex) {
			return 1;
		}
			return 1;
		}
		currentIndex += bytesWritten;
	}

	if (presentMask & BIT_GND_TEMP) {
		int16_t gtemp = (int16_t)((uint16_t)array[19] | ((uint16_t)array[20] << 8));
		bytesWritten = snprintf(result + currentIndex, resultSize - currentIndex, "S=%d.%02d",
				gtemp / 100, abs(gtemp % 100));
		if (bytesWritten < 0 || bytesWritten >= resultSize - currentIndex) {
			return 1;
		}
		currentIndex += bytesWritten;
	}

	if (presentMask & BIT_GND_HUM) {
		uint16_t ghum = (uint16_t)array[21] | ((uint16_t)array[22] << 8);
		bytesWritten = snprintf(result + currentIndex, resultSize - currentIndex, "V=%u.%02u",
				ghum / 100, ghum % 100);
		if (bytesWritten < 0 || bytesWritten >= resultSize - currentIndex) {
			return 1;
		}
		currentIndex += bytesWritten;
	}
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

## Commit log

2023-06-26 ADD - sensor code for nrf52833
2023-06-26 ADD - schematic for the sensor
2023-06-26 FIX - python not trying to reconnect
    [main.py]
2023-06-27 FIX - messages where not sending negative values
    [main.py]
2023-11-21 MOD : Updated board config
2023-11-29 FIX : Flashing firmware
    [main.c]
2023-11-29 ADD : Central is now printing the current value on the pi
2023-11-29 FIX - extra ()
    [main.py]
2023-12-06 FIX : High data usage for sending logs
    [main.py]
2023-12-06 ADD : Mac address filtering
2023-12-07 FIX : Constant name
    [main.c]
2023-12-21 MOD : Higher GND Hum sensibility
2023-12-21 ADD : GND_HUM_V1 calibrated
    [GND_HUM_V1.xlsx]
2023-12-29 MOD : Added filter for "^["
2024-01-02 code quon a flash sur les capteurs qui marche
2024-01-05 modification device + add bleakScanning to do with bluetooth
2024-01-05 trying to fix the start bleak loop
    [bleakScanning.py, main.py]
2024-01-08 ADD : LED and Button drivers
2024-01-08 ADD : Button to wake up and Start DFU
2024-01-09 FIX : AHT20 not reading
    [aht20.c]
2024-01-16 FIX - round values before pushing to alivecode
    [main.py]
2024-01-17 MOD : New device index
2024-01-18 MOD : Sensor sleep on disconection
2024-01-18 FIX - bluetooth connection and changed lrimaconn -> lrima
    [bleakScanning.py, main.py]
2024-01-18 FIX : Sensor stuck in loop
2024-01-19 ADD : Dongle Myrio support via UART
2024-01-22 MOD : Disable UART RX
2024-01-23 added offline mode
    [data.csv]
2024-01-24 MOD : Auto switch i2c and ADD : SHT21 SHT31
2024-01-24 add - pm2 configs for py
    [data.csv]
2024-01-24 ADD : Support for multiple relays
2026-03-11 ADD - Changes made from rasp centrale
    [data.csv]
2026-03-11 FIX - python err
    [bleakScanning.py]
2026-03-11 FIX - python err again
    [bleakScanning.py]
2026-03-11 MOD - PRINTS for central
    [data.csv]
2026-03-11 MOD - less colors in print
2026-03-11 MOD : DFU mode on until button released
2026-03-11 ADD : new schematics versions
2026-03-11 MOD : delay before i2c init
2026-03-11 FIX - Bug with ksleep before init aht
    [main.c]
2026-03-11 MOD - Calibration values
2026-03-11 MOD - Inverted coefficient order in overlay
    [adc.c]
2026-03-11 ADD - Camera script for taking pictures
2026-03-11 FIX - Not receiving data from sensor when it has been reset
    [bleakScanning.py]
2026-03-11 ADD : 5 Relay Board
2026-03-11 FIX : Mistake in 5 relay implementation
    [main.cpp]
2026-03-11 ADD - 3D model for sensor casing
2026-03-11 Add fusion models of sensor casing
    [Full.f3z]
2026-03-11 Add bottom and top part of sicro-sensor casing
    [BottomPart.f3d, TopPart.f3d]
2026-03-11 DEL - Useless models
    [Full.f3z]
2026-03-11 FIX : Inverted Relays
    [main.cpp]
2026-03-11 Add files via upload
    These are the new version of the sensor-casig as of the 15th of december do not print the bottom file with support or the ground will not fit
    [BottomPart3.STL, TopPart2.SLDPRT, TopPart3.STL]
2026-03-11 Add multiple SSID for the relay connection
2026-03-11 Correction des modèles (mesures)
    [BottomPart3.stl, TopPart3.stl]
2026-03-11 ADD - Sleep value will now be always up to date
    [BottomPart3.stl, TopPart3.stl]
2026-03-11 MOD : Better ground temp reading
2026-03-11 FIX - Sleep value is not changed if not connected to ALIVEcode
    [bleakScanning.py, main.py]
2026-03-11 ADD - Reboot after not receiving data for 24h
    [bleakScanning.py]
2026-03-11 Add reboot after a week to the sensor code
    [main.c]
2026-03-11 Add reboot after a week for the broadcaster
    [main.c]
2026-03-11 ADD - Central additional reboot fallback
    [bleakScanning.py]
2026-03-11 MOD - Reset timer for central updated from 24hr to 12hr
    [bleakScanning.py]
2026-03-11 FIX - Console log spam
    [bleakScanning.py]
2026-03-11 Cases testés et fonctionnels
    [BottomPartWithSolar.stl, TopPart3.stl]
2026-03-11 ADD - Better centrale reboot after not receiving data (1 HOUR)
    [bleakScanning.py, main.py]
2026-03-11 Revert changes for the broadcaster
    [adc.c]
2026-03-11 Restore TopPart3.stl after case reset
    [TopPart3.stl]
2026-03-11 FIX: Issue #5 (#6)
    * FIX : Scanning stopping issue
    MOD: readme to install BlueZ 5.82
    REM: sudo reboot
    ADD: restart of the pm2 and bluetooth driver
    CLEAN: BleakScanning
    FIX: Conneciton issues
    * REM: Ignoring empty address message
    * FORMAT: Code is now formated
    * REM : Bad files
    * FIX : Lib name
    * FIX : Issue in queue
    * HANDLE: Connection closed error
    * Update code/central/readme.md
    * Update code/central/bleakScanning.py
    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
    [bleakScanning.py, main.py, reader.py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]
2026-03-11 MOD : Quit central after reboot
    [bleakScanning.py, main.py]
2026-03-11 FIX : Add sys import in main.py
    [main.py]
2026-03-11 FIX : add import sys in bleak scanning
    [bleakScanning.py]
2026-03-11 FIX : last received time
    [bleakScanning.py, main.py]
2026-03-11 FIX : time in bleakScanning
    [bleakScanning.py]
2026-03-11 feat(pcb): Add kicad version of main and ground board
    [lrima-ground.kicad-6inchs_pcb.kicad_pcb, lrima-ground.kicad_pcb, lrima-ground.kicad_sch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]
2026-03-11 fix(pcb): Changed ALIVE to LRIMa
    [lrima-ground.kicad-6inchs_pcb.kicad_pcb, lrima-ground.kicad_pcb, lrima-main.kicad_pcb]
2026-03-29 feat: migrate broadcaster from NCS 2.4 to 3.2.4 (sysbuild + board + DFU)
    move project to NCS 3.2.4 toolchain/build flow and sysbuild-based multi-image setup
    add/update custom board definition for lrima_greenhouse_nrf52833/nrf52833
    migrate MCUboot configuration to sysbuild-level options and image-local mcuboot config
    switch app/DFU configuration to current MCUmgr transport options
    adopt VERSION-based MCUboot image versioning (drop legacy image-version config usage)
    align DTS/I2C configuration with current nRF TWIM usage
    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
2026-03-29 feat: add SHT4X and STCC4 sensor support with logging configuration
2026-03-29 feat: add CO2 sensor support and update data handling in main application
2026-03-29 feat: Add core modules for central runtime orchestration
    - Implemented AliotSyncManager for handling sensor data synchronization with Aliot and offline CSV buffering.
    - Created InactivityWatchdog to monitor service inactivity and restart if necessary.
    - Developed SensorPayloadDecoder for decoding sensor payloads from BLE packets.
    - Added LastReceivedTimeStore and OfflineCsvBuffer for timestamp persistence and offline data buffering.
    - Introduced discover_devices script for scanning BLE devices.
    - Established shared configuration constants in config.py.
2026-03-29 feat: Update bleak dependency version and enhance scanner initialization with GATT error handling
    [bleakScanning.py]
2026-04-04 feat: Enhance broadcaster functionality with payload encoding and BLE state management
    - Added payload encoding module for BLE advertisement data in `payload.c` and `payload.h`.
    - Introduced BLE state machine in `ble.h` and implemented state transitions in `ble.c`.
    - Updated `CMakeLists.txt` to include new source files for payload handling.
    - Enhanced button driver to utilize semaphore for button press events.
    - Improved main application logic to handle sleep time and button press more effectively.
    - Created separate debug and release configurations for optimized builds.
    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
2026-04-04 feat: Update LED driver initialization and error handling; add SHTC3 sensor configuration
    [led.c]
2026-04-04 fix: Correct indentation for SHTC3 sensor configuration in overlay file
2026-04-04 feat: Implement application settings persistence for sleep time, device name, and MAC address
2026-04-04 fix: Improve error handling and logging for sensor readings in the read function
    [main.c]
2026-04-06 fix: Refactor USB adapter detection logic for improved reliability
    [bleakScanning.py]
2026-04-06 fix: Enhance error handling for sensor readings and improve logging
    [main.c, stcc4.c]
2026-06-07 Dev/new broadcast (#10)
    * fix: Fix BLE payload decoding by prepending company ID bytes
    The Bleak BLE scanner provides service_data as a dictionary where:
    - Key: Company ID (0x0059)
    - Value: Service data bytes (without company ID)
    The SensorPayloadDecoder expected the full 25-byte payload with company ID
    at indices [0:2]. When the decoder received only 23 bytes of data without
    the company ID, the company ID check failed (0x0043 != 0x0059), causing it
    to fall back to legacy decoding which doesn't match the fixed frame format.
    This fix reconstructs the full 25-byte payload by extracting the company ID
    from the service_data dictionary key and prepending it (in little-endian
    format) before pas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
    [bleakScanning.py, device.py]
2026-06-08 simple script for camera interaction from web requests through pm2
2026-06-08 feat: added setup script that might or might not work for camera dependencies and configs
2026-06-08 feat: add function to blink LED1 for a specified duration
